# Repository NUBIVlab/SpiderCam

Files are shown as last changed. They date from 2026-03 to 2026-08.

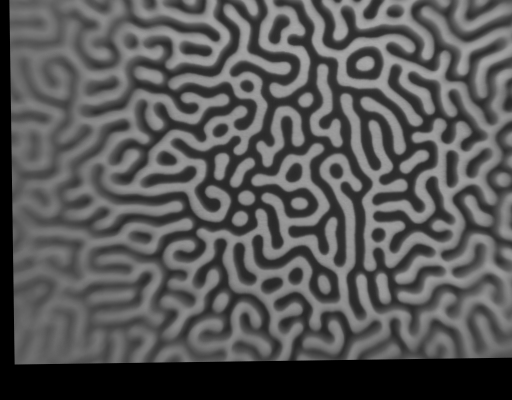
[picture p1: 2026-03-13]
fpga/tb/dfdd_tb/test_images/capture_22_camera1.png

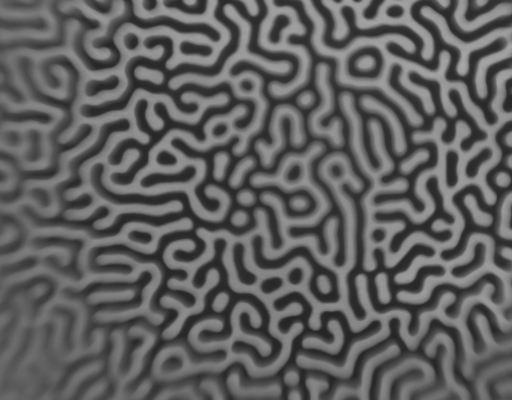
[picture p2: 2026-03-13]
fpga/tb/dfdd_tb/test_images/capture_22_camera0.png

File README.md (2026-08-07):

## [CVPR 2026] SpiderCam: Low-Power Snapshot Depth from Differential Defocus

<b>[Marcos A. Ferreira](https://marc103.github.io/)</b><sup>&ast;,1</sup>, <b>[Tianao Li](https://lukeli0425.github.io/)</b><sup>&ast;,1</sup>, <b>[John Mamish](https://scholar.google.com/citations?user=ux9iJ74AAAAJ&hl=en)</b><sup>&ast;,2</sup>, <b>[Josiah Hester](https://josiahhester.com/)</b><sup>2</sup>, <b>[Yaman Sangar](https://scholar.google.com/citations?user=gbBJzRkAAAAJ&hl=en&oi=ao)</b><sup>2</sup>, <b>[Qi Guo](https://www.qiguo.org/)</b><sup>3</sup>, <b>[Emma Alexander](https://www.alexander.vision/emma)</b><sup>1</sup>
<br>
<sup>1</sup>Northwestern University, <sup>2</sup>Georgia Institute of Technology, <sup>3</sup>Purdue University, <sup>&ast;</sup>Equal contribution.

_IEEE/CVF Conference on Computer Vision and Pattern Recognition (CVPR), 2026_

&nbsp;
&nbsp;
&nbsp;
&nbsp;

Official code for [_SpiderCam: Low-Power Snapshot Depth from Differential Defocus_](https://nubivlab.github.io/SpiderCam/).

Pipeline

### Repository layout

| Path | Contents |
| --- | --- |
| [`configs/`](configs/), [`datasets/`](datasets/), [`models/`](models/), [`utils/`](utils/) | Hydra configs and DfDD training / inference code |
| [`serialcam_ft232h/`](serialcam_ft232h/) | Live FT232H stream viewer and on-device DfDD parameter UI |
| [`fpga/`](fpga/) | FPGA RTL (see [`fpga/README.md`](fpga/README.md)) |
| [`pcb/`](pcb/) | PCB layouts |
| [`3d_printed_parts/`](3d_printed_parts/) | Printable enclosure parts |

### Running DfDD

#### Setup

To install required packages:
```bash
pip install -r requirements.txt
```

#### Data

Point `data_path` in a config under [`configs/data/`](configs/data/) to your capture directory. Each group folder should contain paired frames:

- `cam_1_500_480_{idx}.png` — near-focus (`+`) image  
- `cam_0_500_480_{idx}.png` — far-focus (`-`) image  

Crop, frame range, depth step/offset, and image center are set in the same YAML (see e.g. [`configs/data/11-06.yaml`](configs/data/11-06.yaml)).

#### Model parameters

Defaults live in [`configs/model/focal_split.yaml`](configs/model/focal_split.yaml). Override any of them on the CLI with Hydra (`model.<key>=...`).

| Parameter | Options / typical values | Meaning |
| --- | --- | --- |
| `model.n_scales` | `1` or `2` | Number of Laplacian-pyramid levels. Depth is estimated at each scale and fused; `2` is the paper default and improves robustness across texture frequencies. |
| `model.dxdy` | `true` / `false` | If `true`, append spatial derivatives (`∂/∂x`, `∂/∂y`) of `V` and `W` as extra channels before fusion (3 channels per scale). Helps on oriented textures. |
| `model.const` | `rings`, `universal`, `radial`, `polynomial`, `pixel-grid` | How optical constants **A** and **B** vary over the field of view (see below). |
| `model.n_rings` | e.g. `16` | Used when `const=rings`: number of concentric annuli with a shared (A, B) per ring. |
| `model.n_orders` | e.g. `2` | Used when `const=radial` or `polynomial`: polynomial degree of the radial / 2D field. |
| `model.conf` | `VW`, `W2`, `V`, `W` | Confidence map used for sparsity filtering and (in `separate` mode) scale fusion. |
| `model.mode` | `joint` / `separate` | How multi-channel estimates are fused (see below). |

**Optical constants (`model.const`).** DfDD recovers depth from a linear combination of the image Laplacian and the differential image, with learnable maps **A** and **B** (one pair per scale):

- `universal` — single scalar (A, B) per scale (spatially constant; ablation / simplest FPGA mapping).
- `rings` — piecewise-constant (A, B) on concentric rings about `data.center` (paper default; matches on-device zone tables).
- `radial` — A(r), B(r) as low-order polynomials in image radius.
- `polynomial` — full 2D polynomial in (x, y).
- `pixel-grid` — independent (A, B) at every pixel (most flexible, heaviest).

**Confidence (`model.conf`).** With numerator/denominator terms built from `V` and `W`:

- `VW` — confidence ∝ `V·W` (paper default; aligns with the depth numerator).
- `W2` — confidence ∝ `W²` (denominator energy).
- `V` / `W` — confidence ∝ `|V|` or `|W|`.

Higher confidence pixels are kept when evaluating at a given sparsity (see `optim.sparsity`).

**Fusion (`model.mode`).** Softmax weights `ω` combine channels across scales (and dx/dy if enabled):

- `joint` — fuse numerator and denominator first, then divide (more stable; default).
- `separate` — form a depth map per channel, then confidence-weighted average.

**Paper setting (recommended start):**

```text
model.n_scales=2 model.dxdy=true model.mode=joint model.const=rings model.n_rings=16 model.conf=VW
```

#### Train

Calibrate / train optical constants with Hydra overrides:

```bash
python train_focal_split.py data=11-06 data.group=texture1 \
  model.n_scales=2 model.dxdy=true model.mode=joint model.const=rings model.n_rings=16 \
  model.conf=VW
```

Checkpoints and logs are written under `./results/`. For the full ablation suite used in the paper, see [`train.sh`](train.sh).

#### Evaluate

After training, run inference with the same data/model/optim settings (must match the trained checkpoint path):

```bash
python run_focal_split.py data=11-06 data.group=texture1 \
  model.n_scales=2 model.dxdy=true model.mode=joint model.const=rings model.n_rings=16 \
  model.conf=VW
```

This loads `checkpoint_{n_epochs}epochs.pth`, reports MAE/MSE and working range at several sparsities, and saves heatmaps / depth maps under `./results/`.

#### Live hardware (optional)

With the SpiderCam FPGA connected over FT232H:

```bash
python serialcam_ft232h/serialcam_stream_ft232h.py
```

Requires the `serialcam` stack (PyQt5, `ftd2xx`). Use **Set DfDD Parameters** in the viewer to push A/B/ω and confidence thresholds to the device. 
<!-- PCB layouts, FPGA RTL, and printable enclosure parts are under [`pcb/`](pcb/), [`fpga/`](fpga/), and [`3d_printed_parts/`](3d_printed_parts/). -->

### Citation

```bibtex
@InProceedings{ferreira2026spidercam,
    author    = {Ferreira, Marcos A. and Li, Tianao and Mamish, John and Hester, Josiah and Sangar, Yaman and Guo, Qi and Alexander, Emma},
    title     = {SpiderCam: Low-Power Snapshot Depth from Differential Defocus},
    booktitle = {Proceedings of the IEEE/CVF Conference on Computer Vision and Pattern Recognition (CVPR)},
    month     = {June},
    year      = {2026},
    pages     = {41699-41709}
}
```

### Acknowledgment

This research was partially supported by the National Science Foundation under award numbers CNS-2430327 and CCF-2431505. Any opinions, findings, conclusions, or recommendations expressed in this material are those of the authors and do not necessarily reflect the views of the National Science Foundation or other supporters. We would also like to thank [Junjie Luo](https://luo-jun-jie.github.io/) and [Alan Fu](https://www.linkedin.com/in/alan-fu-a100b91a5/) for helpful discussions.

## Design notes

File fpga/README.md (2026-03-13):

# Floating Point Image Processing SV RTL

Contains parameterized floating point\
- adder\
- multiplier\
- divider

Parameterized as in you can select a custom number of bits for exponent
and fractional parts i.e to support FP16 or FP32 (or anything above and
in between like FP24). It's almost to the IEEE-754 with the exceptions
of disabling subnormal number support and the rounding isn't perfect
(ties always round up and instead of having a round and guard bit, there
is just a round bit). This was done to make it more area efficient when
deploying on FPGA platforms.

There is also the modules\
- window fetcher\
- convolution floating point

The window fetcher grabs a window of values from a data stream (such as
a pixel stream). The convolution module takes a window of values and a
kernel and performs the convolution (MAC operation). Since kernels are
often sparse matrices and/or with powers of 2, there is also the
`optimal_convolution_floating_point_generator.py` in the tools folder
which generates the necessary wrappers to optimize away 0 values for
multiplies and consequently the sparse adder trees. View the python file
itself to see how to call it.

By combining these building blocks modules, we can build networks of
convolution filters with the data streaming model. This is showcased in
the DfDD project.

------------------------------------------------------------------------

# Folder Structure

### rtl

Contains RTL code.

### → third_party

Contains third party RTL code.

### → verify_files

Verifying that my floating point modules are correct is tricky business.
Thus on top of using formal equivalence verification (by comparing my
results to the CPU's results), I also wrote these informal
`verify_files` that detail steps I took, which I then proof read some
number of times.

### tb

Contains all relevant testbench code done using Formal Equivalence
Verification (FEV). This is a fancy way of saying I compared the DUT
results to theoretical golden models as a verification methodology. It
is structured and decoupled in a way that makes most sense to me and is
generally applicable.

### → components

Organized the standard components that using the OOP part of
SystemVerilog is built and quite handy for; drivers, generators, golden
models, interfaces, monitors, scoreboards and utilities, package
manager.

Very briefly, it follows the Bus Functional Model (BFM) where you pass
the main interface as a virtual interface to the named components and
connect these components via blocking queues as seen in each of the
`*_tb` subfolders that correspond to the DUT.

### → \*\_tb/simulate

Contains the script to run the simulation on ModelSim (specifically
through Diamond).

### synth

This contains all the synthesis folders. The synthesis folders contain
the final `top` files and various scripts to perform synthesis.

In this case, the folders are targeted towards the ECP5 FPGA using
Yosys's Trellis Project + Nextpnr\
https://github.com/YosysHQ/prjtrellis

### Tools

Mainly python scripts that do useful things (like my optimal convolution
generator) and miscellaneous tasks.

------------------------------------------------------------------------

# Bitstreams and Running the GUI

The FPGA bitstream used to program the board must correspond to how the
GUI is configured. The GUI expects a specific data format depending on
which processing pipeline is programmed onto the FPGA.

## Bitstream Variants

### dual_scale → dxdy → radial → pre → top.bit

This bitstream configures the pipeline with:

-   Dual-scale network enabled\
-   `dx` and `dy` filters enabled\
-   Radial `a/b` terms enabled\
-   Preprocessing performed in hardware\
-   Slow frame rate mode

Outputs **two windows**:

-   `cam_0`
-   Depth output

------------------------------------------------------------------------

### dual_scale → pass → simple → nopre → top.bit

This bitstream configures the pipeline with:

-   Dual-scale network enabled\
-   `dx` and `dy` filters disabled\
-   Single (non-radial) `a/b` term\
-   No preprocessing\
-   Slow frame rate mode

Outputs **two windows**:

-   `cam_0`
-   Depth output

------------------------------------------------------------------------

### camera_previewer → top.bit

This bitstream encodes logic that simply passes through `cam_0` and
`cam_1` without any processing.

It runs at slow frame rate and outputs **two windows**.

This configuration is useful when capturing raw sensor data for
processing or performing homography calibration between the two cameras.

------------------------------------------------------------------------

### pre_fast variants

The `pre_fast` versions enable the high frame rate pipeline (\~30 FPS).

In this configuration the system outputs **a single window** containing
only the depth output.

------------------------------------------------------------------------

# Running the GUI

Depending on the programmed bitstream, the GUI must be launched with the
correct number of channels and frame-rate mode.

### Two output windows (slow frame rate mode)

``` bash
python .\serialcam_stream_ft232h.py --width 500 --height 480 --maxchannels 2 --fast 0
```

Displays:

-   `cam_0`
-   depth output

------------------------------------------------------------------------

### One output window (fast frame rate mode)

``` bash
python .\serialcam_stream_ft232h.py --width 500 --height 480 --maxchannels 1 --fast 1
```

Displays:

-   depth output only (high frame rate mode)

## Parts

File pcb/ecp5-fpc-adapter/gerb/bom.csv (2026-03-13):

Reference | Value | Datasheet | Footprint | Qty | DNP
C1,C2,C3,C4 | 10u | ~ | Capacitor_SMD:C_0603_1608Metric_Pad1.08x0.95mm_HandSolder | 4
C5,C6,C7,C8,C9,C10 | 1u | ~ | Capacitor_SMD:C_0603_1608Metric_Pad1.08x0.95mm_HandSolder | 6
J1,J2 | Conn_02x20_Odd_Even | ~ | Connector_PinHeader_2.54mm:PinHeader_2x20_P2.54mm_Vertical | 2
J3,J4 | 5051103091 | 5051103091 | molex_5051:CON_5051103091_MOL | 2
J5,J6,J7 | Conn_01x02_Pin | ~ | Connector_PinHeader_2.54mm:PinHeader_1x02_P2.54mm_Vertical | 3
JP1,JP4,JP5,JP7,JP8,JP9,JP10,JP11,JP12,JP13,JP15 | Jumper_2_Small_Open | ~ | Jumper:SolderJumper-2_P1.3mm_Open_RoundedPad1.0x1.5mm | 11
JP2,JP3,JP6,JP14 | Jumper_2_Small_Bridged | ~ | Jumper:SolderJumper-2_P1.3mm_Bridged_RoundedPad1.0x1.5mm | 4
L1,L2 | 2.2u | ~ | L_2016:IND_DFE2016_MUR | 2
R4,R5,R6,R7 | 10k | ~ | Resistor_SMD:R_0603_1608Metric_Pad0.98x0.95mm_HandSolder | 4
R12,R14,R19,R21 | 100k | ~ | Resistor_SMD:R_0603_1608Metric_Pad0.98x0.95mm_HandSolder | 4
R13 | 28.7k | ~ | Resistor_SMD:R_0603_1608Metric_Pad0.98x0.95mm_HandSolder | 1
R15,R20,R26 | 0 | ~ | Resistor_SMD:R_0603_1608Metric_Pad0.98x0.95mm_HandSolder | 3
R22 | 12k | ~ | Resistor_SMD:R_0603_1608Metric_Pad0.98x0.95mm_HandSolder | 1
R23 | 2k | ~ | Resistor_SMD:R_0603_1608Metric_Pad0.98x0.95mm_HandSolder | 1
U1,U2 | TPS62841DLCR | TPS62840DLCR | tps62840:VSON8_2P1X1P6_TEX | 2
U3 | AP7331-SNG-7 |  | AP7331-SNG-7:DFN200X200X60-8N | 1

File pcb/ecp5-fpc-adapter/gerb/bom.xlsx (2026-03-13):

Reference | Value | Datasheet | Footprint | Qty | mfr pn
C1,C2,C3,C4 | 10u | ~ | Capacitor_SMD:C_0603_1608Metric_Pad1.08x0.95mm_HandSolder | 4 | CL10A106MA8NRNC
C5,C6,C7,C8,C9,C10 | 1u | ~ | Capacitor_SMD:C_0603_1608Metric_Pad1.08x0.95mm_HandSolder | 6 | CL10B105KO8NNNC
J1,J2 | Conn_02x20_Odd_Even | ~ | Connector_PinHeader_2.54mm:PinHeader_2x20_P2.54mm_Vertical | 2 | PPTC202LFBN-RC
J1,J2 |  |  |  | 1 | ESQ-120-14-T-D
J3,J4 | 5051103091 | 5051103091 | molex_5051:CON_5051103091_MOL | 2 | 5051103091
J5,J6,J7 | Conn_01x02_Pin | ~ | Connector_PinHeader_2.54mm:PinHeader_1x02_P2.54mm_Vertical | 3 | M20-9990245
jumper |  |  |  | 10 | QPC02SXGN-RC
L1,L2 | 2.2u | ~ | L_2016:IND_DFE2016_MUR | 2 | DFE201612E-2R2M=P2
R4,R5,R6,R7 | 10k | ~ | Resistor_SMD:R_0603_1608Metric_Pad0.98x0.95mm_HandSolder | 4 | RC0603FR-0710KL
R12,R14,R19,R21 | 100k | ~ | Resistor_SMD:R_0603_1608Metric_Pad0.98x0.95mm_HandSolder | 4 | RC0603FR-07100KL
R13 | 28.7k | ~ | Resistor_SMD:R_0603_1608Metric_Pad0.98x0.95mm_HandSolder | 1 | RC0603FR-0728K7L
R15,R20,R26 | 0 | ~ | Resistor_SMD:R_0603_1608Metric_Pad0.98x0.95mm_HandSolder | 3 | RC0603JR-070RL
R22 | 12k | ~ | Resistor_SMD:R_0603_1608Metric_Pad0.98x0.95mm_HandSolder | 1 | RC0603FR-0712KL
R23 | 2k | ~ | Resistor_SMD:R_0603_1608Metric_Pad0.98x0.95mm_HandSolder | 1 | RC0603FR-072KL
U1,U2 | TPS62841DLCR | TPS62840DLCR | tps62840:VSON8_2P1X1P6_TEX | 2 | TPS62840DLCR
U3 | AP7331-SNG-7 |  | AP7331-SNG-7:DFN200X200X60-8N | 1 | AP7331-SNG-7

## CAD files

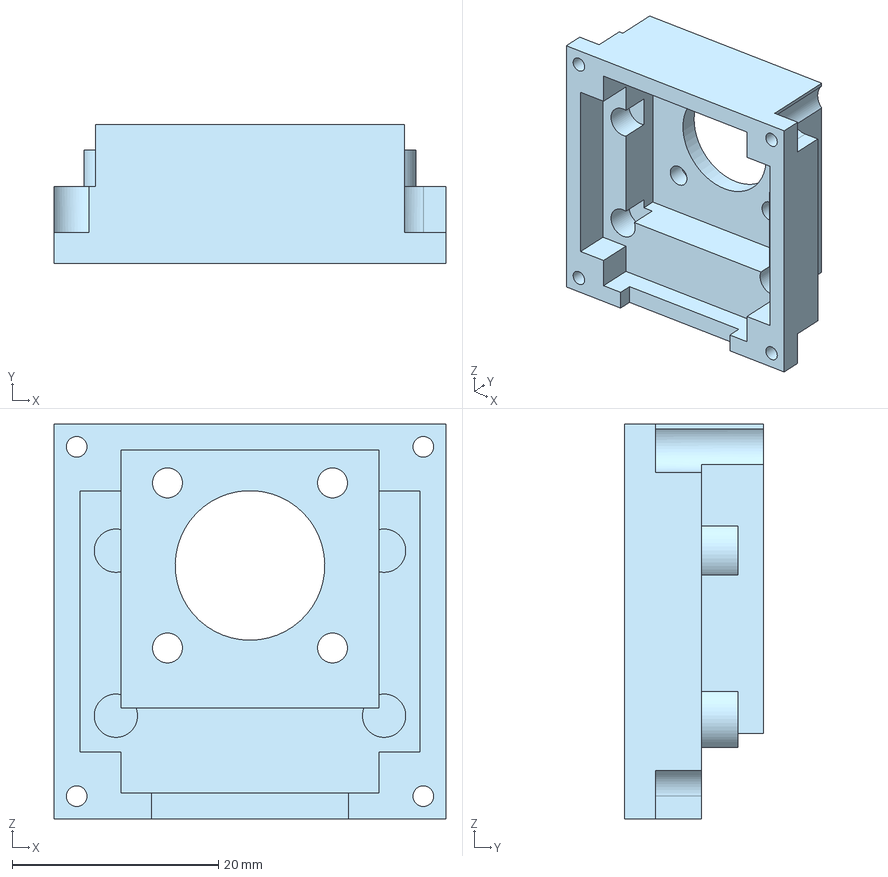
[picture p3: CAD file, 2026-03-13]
3d_printed_parts/dual-sensor-enclosure/Beamsplitter_direct_mount_Baffle.step
38.0 x 13.5 x 38.3 mm

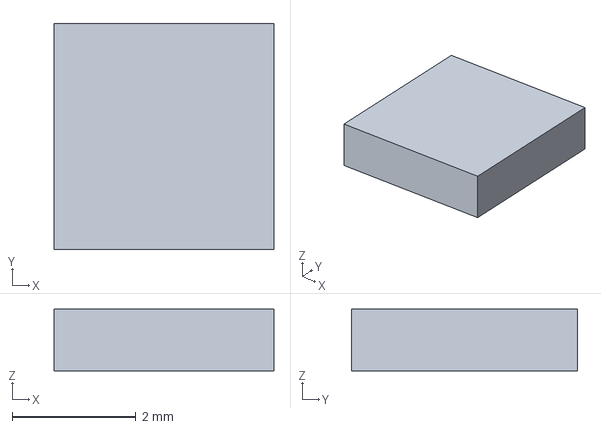
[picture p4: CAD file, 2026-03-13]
pcb/hm0360-carrier/himax_step/hm0360_box.step
3.55 x 3.65 x 1.00 mm

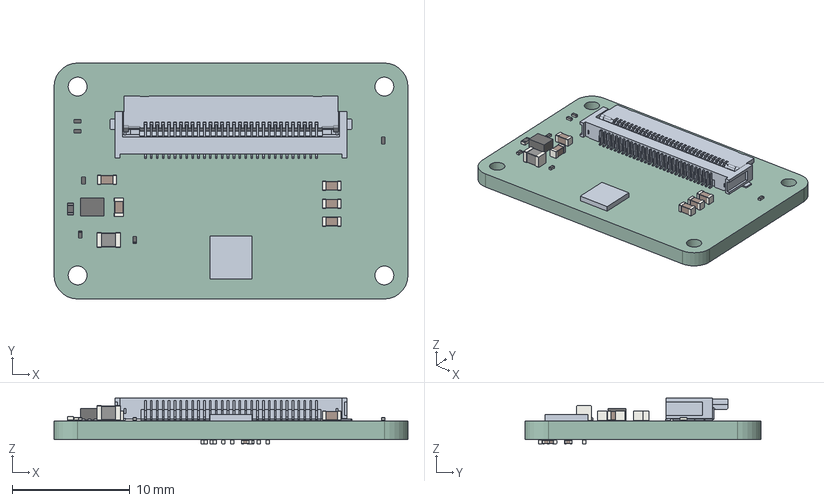
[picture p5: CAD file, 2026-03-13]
pcb/hm0360-carrier/hm0360_breakout.step
30.0 x 20.0 x 3.86 mm
R_0402_1005Metric
C_0603_1608Metric x 5
R_0201_0603Metric x 6
L_0805_2012Metric
DLC0008B_ASM
C_0201_0603Metric x 12
hm0360_breakout_PCB

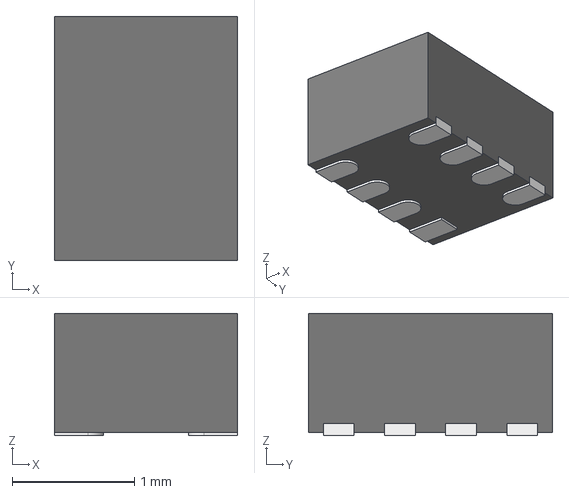
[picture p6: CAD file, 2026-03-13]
pcb/hm0360-carrier/TPS62840DLCR/DLC0008B.stp
1.50 x 2.00 x 1.00 mm
FRAME
MOLD

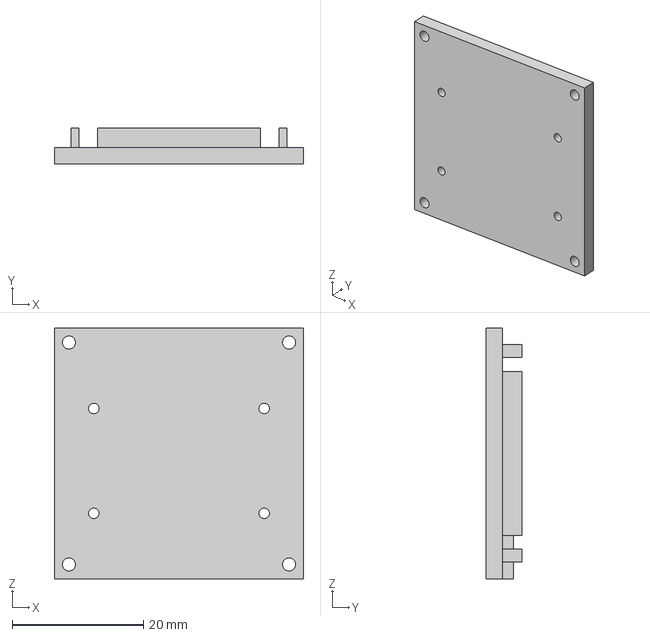
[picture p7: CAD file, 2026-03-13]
3d_printed_parts/dual-sensor-enclosure/Beamsplitter_direct_mount_iris_Lid.step
38.0 x 5.50 x 38.3 mm

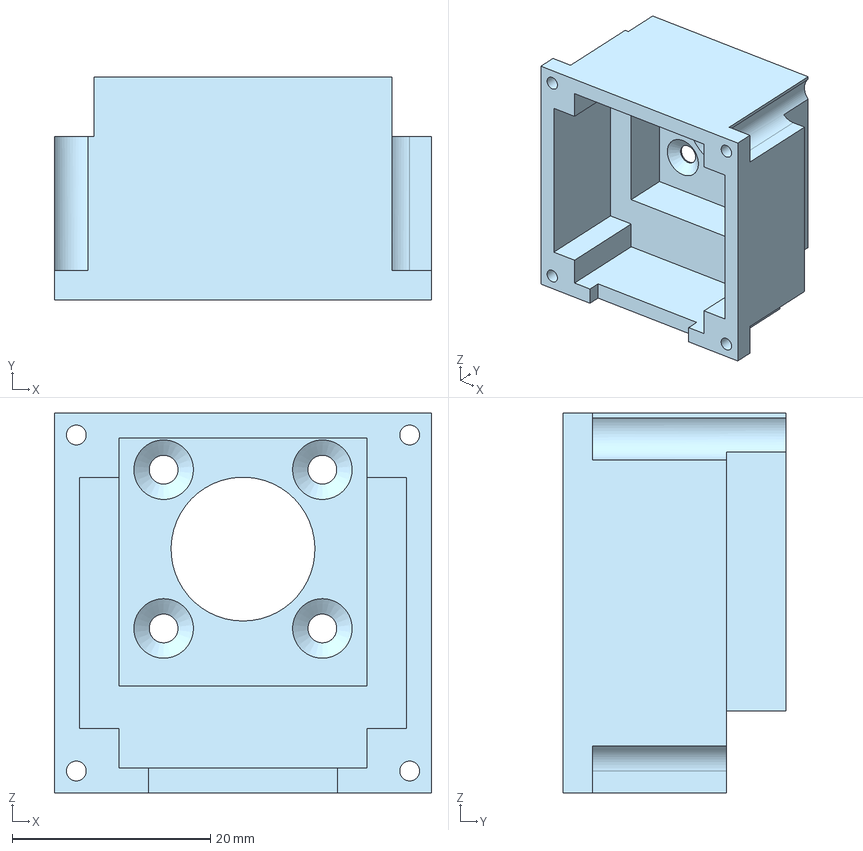
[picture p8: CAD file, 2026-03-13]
3d_printed_parts/dual-sensor-enclosure/Beamsplitter_direct_mount_iris_Baffle.step
38.0 x 22.5 x 38.3 mm

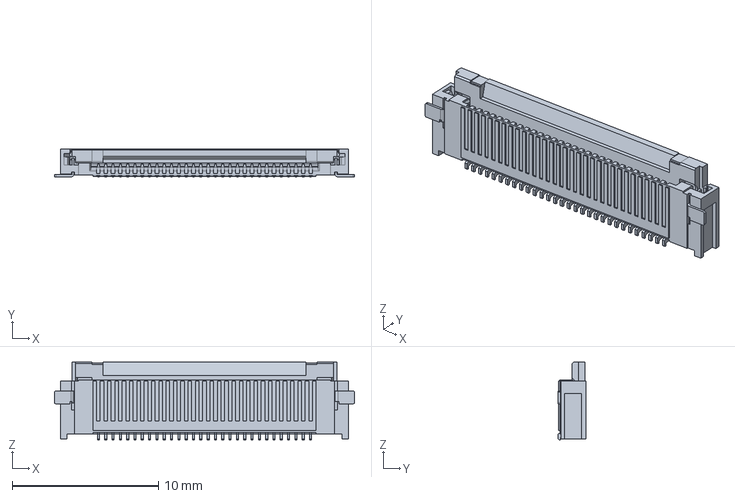
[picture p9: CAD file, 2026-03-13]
pcb/hm0360-carrier/molex_5051103091/5051103091.stp
20.5 x 1.90 x 5.30 mm

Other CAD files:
3d_printed_parts/dual-sensor-enclosure/Beamsplitter_direct_mount_Lid.step

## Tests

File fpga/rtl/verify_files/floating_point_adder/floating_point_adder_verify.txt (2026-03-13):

Floating Point Adder

Specification:
- Wire up all the pieces in the following order:
1. sgm - select greater magnitude
2. ngm - normalize greater magnitude
x x x 3. rnv - round normalized value x x x
3. cvt - convert to signed 
4. avt - add values together
5. cvu - convert to unsigned 
6. nr  - normalize result
7. rr  - round result 

Modification:
- previously I thought the rounding at rnv was necessary
but actually it is premature. Instead it is better to allow
the addition to happen first and let the final rounding do
the job. Therefore, 'rnv' has been removed adnt this is now
a 7 stage pipelined adder.

Parameters:
- EXP_WIDTH,  width of exponent part                                    
- FRAC_WIDTH, width of fractional part

'Local' Parameters:                                                                
- FP_WIDTH_TOT, width of total form fp
    -> 1 + EXP_WIDTH + FRAC_EX_WIDTH                            _*_                           
- FP_WIDTH_REG, width of regular form fp 
    -> 1 + EXP_WIDTH + 1 + 1 + FRAC_WIDTH + 1                   _*_

IO:
- check widths                                                  _*_

Wiring:
- naming convention is from_to_*_w                              _*_
- check 1 wires - sgm
    - parameters                                                _*_
    - widths                                                    _*_
    - names                                                     _*_
- check 2 wires - ngm
    - parameters                                                _*_
    - widths                                                    _*_
    - names                                                     _*_
- check 3 wires - cvt
    - parameters                                                _*_
    - widths                                                    _*_
    - names                                                     _*_
- check 4 wires - avt
    - parameters                                                _*_                         
    - widths                                                    _*_
    - names                                                     _*_
- check 5 wires - cvu
    - parameters                                                _*_                                                   
    - widths                                                    _*_
    - names                                                     _*_ 
- check 6 wires - nr
    - parameters                                                _*_
    - widths                                                    _*_
    - names                                                     _*_
- check 7 wires - rr
    - parameters                                                _*_
    - widths                                                    _*_
    - names                                                     _*_
- check clk_i and rst_i for all                                 _*_

Output:
- check output of rr to top out                                 _*_

Log:
- floating point adder has been verfied once by me (7/10/25)

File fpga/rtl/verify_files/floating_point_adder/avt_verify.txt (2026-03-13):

Add Values Together

Specification:
- given fp_a_i and fp_b_i in total form add them
  together and output the result
- output fp_a_sign and fp_b_sign, this will be necessary
 for cvu (next stage) to determine how to interpret the
 carry bit

Descriptions:
- frac ex (expand) describes carry bit, lead bit, frac bits and round bit
  in that order.
- it's just a way to break up the full form into pieces:
    {sign bit, exp bits, frac ex bits} for ease of use

Parameters:
- EXP_WIDTH,  width of exponent part                                    
- FRAC_WIDTH, width of fractional part                                  

'Local' Parameters:
- FRAC_EX_WIDTH, width of frac ex                       
    -> 1 + 1 + FRAC_WIDTH + 1                                           _*_ _*_                                   
- FRAC_EX_IDX_LSB, lsb index of frac ex 
    -> 0                                                                _*_ _*_                                            
- FRAC_EX_IDX_MSB, msb index of frac ex
    -> FRAC_EX_WIDTH + FRAC_EX_IDX_LSB - 1                              _*_ _*_                      
- EXP_IDX_LSB, lsb index of exp ex
    -> FRAC_EX_WIDTH                                                    _*_ _*_                                                                               
- EXP_IDX_MSB, msb index of exp ex
    -> EXP_WIDTH + EXP_IDX_LSB - 1                                      _*_ _*_                                 
- SIGN_IDX, index of sign bit
    -> EXP_WIDTH + FRAC_EX_WIDTH                                        _*_ _*_                      
- FP_WIDTH_TOT, width of total form fp
    -> 1 + EXP_WIDTH + FRAC_EX_WIDTH                                    _*_ _*_

IO:
- check widths                                                          _*_ _*_ 

Input Registers:
- check widths                                                          _*_ _*_
- fp_a_reg samples fp_a_i @ clk_i                                       _*_ _*_
- fp_b_reg samples fp_b_i @ clk_i                                       _*_ _*_
- if rst_i is high, valid_reg samples 0       @ clk_i                   _*_ _*_
- if rst_i is low,  valid_reg samples valid_i @ clk_i                   _*_ _*_

Main:   
- check widths                                                          _*_ _*_                                      
- sign, exp and frac_ex starting values for fp_*                        _*_ _*_
- sign, frac_ex starting for fp is set to 0s                            _*_ _*_        
- frac_exp for fp is set to fp_exp_a                                    _*_ _*_
- the logic is as such:
    - with the context of the previous round (cvt)                      _*_ _*_
    - the frac_ex values are in signed mode                             _*_ _*_
    - if the sign bits were different, the negative one                 
      is negative
    - if the sign bits are the same, both are positive                  _*_ _*_
    - meaning, if the sign bits are the same, if they are               _*_ _*_
      added, the carry bit is a genuine carry bit
    - if the sign bits are different,                                   _*_ _*_
        - an overflow is impossible, since one value is positive
          and the other negative
        - the carry bit actually represents the resulting sign
          of the addition
    - this also means, for the output, we need to pass the              _*_ _*_
      fp_a_sign adn fp_b_sign, so the next stage knows how
    - to interpret it
    - + is fine                                                         _*_ _*_

Output:
- fp_o is concatenation of fp_sign, fp_exp and fp_frac_exp              _*_ _*_
- fp_a_sign_o is fp_a_sign                                              _*_ _*_
- fp_b_sign_o is fp_b_sign                                              _*_ _*_
- valid_o is valid_reg                                                  _*_ _*_

Log:
- avt has been verified by me (7/9/25)
- avt has been verified by me (7/14/25)

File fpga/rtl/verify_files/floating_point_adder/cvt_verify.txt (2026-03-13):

Convert to signed

Specification:
- given fp_a_i and fp_b_i in total form, using the sign bits, convert
  the frac exp of each to its signed version if the sign bits differ, 
  in prepartion for the addition step

Descriptions:
- frac ex (expand) describes carry bit, lead bit, frac bits and round bit
  in that order.
- it's just a way to break up the full form into pieces:
    {sign bit, exp bits, frac ex bits} for ease of use

Parameters:
- EXP_WIDTH,  width of exponent part                                    
- FRAC_WIDTH, width of fractional part                                  

'Local' Parameters:
- FRAC_EX_WIDTH, width of frac ex                       
    -> 1 + 1 + FRAC_WIDTH + 1                                           _*_ _*_           
- FRAC_EX_IDX_LSB, lsb index of frac ex 
    -> 0                                                                _*_ _*_
- FRAC_EX_IDX_MSB, msb index of frac ex
    -> FRAC_EX_WIDTH + FRAC_EX_IDX_LSB - 1                              _*_ _*_
- EXP_IDX_LSB, lsb index of exp ex
    -> FRAC_EX_WIDTH                                                    _*_ _*_                                          
- EXP_IDX_MSB, msb index of exp ex
    -> EXP_WIDTH + EXP_IDX_LSB - 1                                      _*_ _*_
- SIGN_IDX, index of sign bit
    -> EXP_WIDTH + FRAC_EX_WIDTH                                        _*_ _*_
- FP_WIDTH_TOT, width of total form fp
    -> 1 + EXP_WIDTH + FRAC_EX_WIDTH                                    _*_ _*_

IO:
- check widths                                                          _*_ _*_

Input Registers:
- check widths                                                          _*_ _*_
- fp_a_reg samples fp_a_i @ clk_i                                       _*_ _*_
- fp_b_reg samples fp_b_i @ clk_i                                       _*_ _*_
- if rst_i is high, valid_reg samples 0       @ clk_i                   _*_ _*_
- if rst_i is low,  valid_reg samples valid_i @ clk_i                   _*_ _*_

Main:
- check widths                                                          _*_ _*_
- sign, exp and frac_ex starting values                                 _*_ _*_

then

- the logic is as such:
    - with the context of the previous round (rnv)                      _*_ _*_
    - carry bit is 0                                                    _*_ _*_
    - lead bit is either 1 or 0                                         _*_ _*_
    - if the sign bits are the same, then we can maintain               _*_ _*_
      both frac ex as they are
    - if the sign bits differ, then the negative sign one needs         _*_ _*_
      to be converted by performing complement + 1
    - the idea here is adding the frac ex directly is fine              _*_ _*_
      when the signs are the same (it's just magnitudes). If they
      differ, one being converted will guarantee that when they are
      added together, than an overflow will not occur since we
      are adding a positive and negative value together.
    - We can then use the sign bits to determine later whether          _*_ _*_
      the carry bit should be interpreted as an actual carry bit
      or sign bit (as will be written in the avt_verify.txt file)
    - ~ is fine                                                         _*_ _*_
    - + 1 is fine                                                       _*_ _*_
    - != is fine                                                        _*_ _*_
 
Output:
- fp_*_o is the concatenation of fp_*_sign, fp_*_exp and fp_*_frac_ex   _*_ _*_
- valid_o is valid_reg                                                  _*_ _*_

Log:
- cvt has been verified by me (7/9/25)
- cvt has been verified by me (7/14/25)

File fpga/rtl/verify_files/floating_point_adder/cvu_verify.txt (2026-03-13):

Convert to unsigned

Specification:
- given fp_i, fp_a_sign_i, fp_b_sign_i, using the sign bits
  fp_frac_ex to a positive value and determine the Finally
  resulting sign bit.

Descriptions:
- frac ex (expand) describes carry bit, lead bit, frac bits and round bit
  in that order.
- it's just a way to break up the full form into pieces:
    {sign bit, exp bits, frac ex bits} for ease of use

Parameters:
- EXP_WIDTH,  width of exponent part                                    
- FRAC_WIDTH, width of fractional part                                  

'Local' Parameters:
- FRAC_EX_WIDTH, width of frac ex                       
    -> 1 + 1 + FRAC_WIDTH + 1                                           _*_ _*_                                             
- FRAC_EX_IDX_LSB, lsb index of frac ex 
    -> 0                                                                _*_ _*_                                                                     
- FRAC_EX_IDX_MSB, msb index of frac ex
    -> FRAC_EX_WIDTH + FRAC_EX_IDX_LSB - 1                              _*_ _*_                                                   
- EXP_IDX_LSB, lsb index of exp ex
    -> FRAC_EX_WIDTH                                                    _*_ _*_                                                                                                 
- EXP_IDX_MSB, msb index of exp ex
    -> EXP_WIDTH + EXP_IDX_LSB - 1                                      _*_ _*_                                                      
- SIGN_IDX, index of sign bit
    -> EXP_WIDTH + FRAC_EX_WIDTH                                        _*_ _*_                                         
- FP_WIDTH_TOT, width of total form fp
    -> 1 + EXP_WIDTH + FRAC_EX_WIDTH                                    _*_ _*_
- CARRY_IDX, idx of carry bit
    -> 1 + FRAC_WIDTH + 1                                               _*_ _*_

IO:
- check widths                                                          _*_ _*_                                         

Input Registers:
- check widths                                                          _*_ _*_                                           
- fp_reg samples fp_i @ clk_i                                           _*_ _*_
- fp_a_sign_reg samples fp_a_sign_i @ clk_i                             _*_ _*_                             
- fp_b_sign_reg smaples fp_b_sign_i @ clk_i                             _*_ _*_
- if rst_i is high, valid_reg samples 0       @ clk_i                   _*_ _*_             
- if rst_i is low,  valid_reg samples valid_i @ clk_i                   _*_ _*_
 
Main:
- check widths                                                          _*_ _*_
- sign, exp, frac_ex starting values for fp_*                           _*_ _*_
- The logic is as such:
    - fp_*_frac_ex are in signed mode, if both sign bits are equal,     _*_ _*_
      resulting carry bit represents an actual carry bit
      - in this case, no conversion is necessary                        _*_ _*_
      - the result sign bit is fp_a_sign_reg                            _*_ _*_
    - if the bits are different, the carry bit represents a sign bit
      - in this case, if the carry bit is 1 (meaning negative value),
        we need to do complemenet + 1 to convert it to positive value   _*_ _*_
        - this also means the result sign bit is 1                      _*_ _*_
      - converting a negative value to positive will never cause an
        overflow, since you can convert a signed value to unsigned
        in the same number of bits                                      _*_ _*_
      - if the carry bit is zero, it is a positive value, no need to    _*_ _*_
        convert
        - this also means the result sign bit is 0                      _*_ _*_
      - There is another important check, if it turns out the result
        is zero, we need to set fp_exp to 0                             _*_ _*_
    
Output
- fp_o is the concatenation of fp_sign, fp_exp and fp_frac_exp          _*_ _*_
- valid_o is valid_reg                                                  _*_ _*_

Log:
- cvu has been verified by me (7/9/25)
- cvu has been verified by me (7/14/25)

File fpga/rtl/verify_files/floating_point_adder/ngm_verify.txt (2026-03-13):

Normalize to Greater Magnitude

Specification:
- given fp_a_i and fp_b_i in total form, where fp_a_i is
guaranteed to have the bigger or equal exponent, raise the exponent value
of fp_b_i to fp_a_i, using exp_diff_i
- output fp_a_o 
and the newly normalized fp_b_o
- output the valid signal, reset valid signal to 0 on reset.

Descriptions:
- frac ex (expand) describes carry bit, lead bit, frac bits and round bit
  in that order.
- it's just a way to break up the full form into pieces:
    {sign bit, exp bits, frac ex bits} for ease of use

Parameters:
- EXP_WIDTH,  width of exponent part                                    _*_
- FRAC_WIDTH, width of fractional part                                  _*_

'Local' Parameters:
- FRAC_EX_WIDTH, width of frac ex
    -> 1 + 1 + FRAC_WIDTH + 1                                           _*_ _*_
- FRAC_EX_IDX_LSB, lsb index of frac ex 
    -> 0                                                                _*_ _*_
- FRAC_EX_IDX_MSB, msb index of frac ex
    -> FRAC_EX_WIDTH + FRAC_EX_IDX_LSB - 1                              _*_ _*_
- EXP_IDX_LSB, lsb index of exp ex
    -> FRAC_EX_WIDTH                                                    _*_ _*_                                           
- EXP_IDX_MSB, msb index of exp ex
    -> EXP_WIDTH + EXP_IDX_LSB - 1                                      _*_ _*_
- SIGN_IDX, index of sign bit
    -> EXP_WIDTH + FRAC_EX_WIDTH                                        _*_ _*_
- FP_WIDTH_TOT, width of total form fp
    -> 1 + EXP_WIDTH + FRAC_EX_WIDTH                                    _*_ _*_                             

IO:
- check widths                                                          _*_ _*_

Input Registers:
- check widths                                                          _*_ _*_
- fp_*_reg samples fp_*_i         @ clk_i                               _*_ _*_
- exp_diff_reg samples exp_diff_i @ clk_i                               _*_ _*_
- if rst_i is high, valid_reg samples 0      @ clk_i                    _*_ _*_
- if rst_i is low, valid_reg samples valid_i @ clk_i                    _*_ _*_

Main:
- check widths                                                          _*_ _*_                         
- sign, exp and frac_ex starting values                                 _*_ _*_

then

- since we are raising fp_b_exp to fp_a_exp, we set fp_b_exp to
  fp_a_exp                                                              _*_ _*_

then

- frac ex consists of [carry bit | lead bit | frac bits | round bit ]   
    - we know the carry bit is zero (from sgm)                          _*_ _*_
    - that means, if we shift by frac bits + 1, the lead bit can end up _*_ _*_
      at the round bit
    - if we shift more than frac bits + 1, the result will be 0         _*_ _*_
    - hence only shift by exp_diff_reg bits if it is <= frac_bits + 1,  _*_ _*_
    - otherwise, set it to 0                                            _*_ _*_
    - a logical shift '>>' is correct here                              _*_ _*_
    - the idea is, for increasing the exponent by 1, we have to divide  _*_ _*_
      the frac ex by 2, hence the right shifting
    - exp_diff_reg must be declared as unsigned, since there is
      potential ambiguity of negative right shift (that could also      _*_ _*_
      cost more hardware), adn the <= comparison aswell.       

Output:
- fp_*_o is the concatenation of the fp_*_sign, fp_*_exp,               _*_ _*_
  fp_*_frac_ex.                                 
- valid_o is valid_reg                                                  _*_ _*_

Log:
- ngm has been verified by me (7/8/25)
- ngm has been verified by me (7/14/25)

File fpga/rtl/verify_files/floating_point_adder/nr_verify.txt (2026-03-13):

Normalize result

Specification:
- given fp_i, we need to normalize it such that the msb is stored
  at the lead bit location
- in this case, the msb refers to the first 1 bit found at the most
  significant bit position (not just the left most bit).

Descriptions:
- frac ex (expand) describes carry bit, lead bit, frac bits and round bit
  in that order.
- it's just a way to break up the full form into pieces:
    {sign bit, exp bits, frac ex bits} for ease of use

Parameters:
- EXP_WIDTH,  width of exponent part                                    
- FRAC_WIDTH, width of fractional part                                  

'Local' Parameters:
- FRAC_EX_WIDTH, width of frac ex                       
    -> 1 + 1 + FRAC_WIDTH + 1                                       _*_ _*_                                                                               
- FRAC_EX_IDX_LSB, lsb index of frac ex 
    -> 0                                                            _*_ _*_                                                                      
- FRAC_EX_IDX_MSB, msb index of frac ex
    -> FRAC_EX_WIDTH + FRAC_EX_IDX_LSB - 1                          _*_ _*_                                                    
- EXP_IDX_LSB, lsb index of exp ex
    -> FRAC_EX_WIDTH                                                _*_ _*_                                                                                                  
- EXP_IDX_MSB, msb index of exp ex
    -> EXP_WIDTH + EXP_IDX_LSB - 1                                  _*_ _*_                                                       
- SIGN_IDX, index of sign bit
    -> EXP_WIDTH + FRAC_EX_WIDTH                                    _*_ _*_                                          
- FP_WIDTH_TOT, width of total form fp
    -> 1 + EXP_WIDTH + FRAC_EX_WIDTH                                _*_ _*_ 
- CARRY_IDX, idx of carry bit
    -> 1 + FRAC_WIDTH + 1                                           _*_ _*_
- LEAD_IDX, idx of lead bit
    -> FRAC_WIDTH + 1                                               _*_ _*_
- EXP_MAX, max value of an exponent (INF)
    -> (2**EXP_WIDTH) - 1                                           _*_ _*_

IO:
- check widths                                                          

Input Registers:
- check widths                                                      _*_ _*_                                                      
- fp_reg samples fp_i @ clk_i                                       _*_ _*_     
- if rst_i is high, valid_reg samples 0       @ clk_i               _*_ _*_         
- if rst_i is low,  valid_reg samples valid_i @ clk_i               _*_ _*_    

Main:
- check widths                                                      _*_ _*_
- sign, exp and frac_ex starting values                             _*_ _*_
- check exp_const is exp starting value                             _*_ _*_
- check frac_ex_const is frac_ex starting value
- exp must be declared as unsigned                                  _*_ _*_                                 
- The logic is as such:
    - with the context of the previous round (cvu), we know         _*_ _*_
      it is in unsigned mode
    - We have to identify where the first 1 bit is located          _*_ _*_
      and do the appropriate shift
    - if the msb 1-bit is the carry bit, increase the exponent by 1 _*__*_
      and perform a right shift                                             
    - else if the msb 1-bit is the lead bit, do nothing             _*_ _*_
    - else if the msb 1-bit is the LEAD_IDX - 1 bit,                _*_ _*_
      decrease the exponent by 1, perform 1 left shift
    - else if the msb 1-bit is the LEAD_IDX - 2 bit,                _*_ _*_
      decrease the exponent by 2, peform 2 left shifts
    - written as the for loop i going from 0 -> LEAD_IDX - 1:       _*_ _*_
        - the number of left shifts is calculated as                _*_ _*_
          (LEAD_IDX - i) == ((FRAC_WIDTH + 1) - i)
        - we see that when i = 0, we shift by FRAC_WIDTH + 1        _*_ _*_    
          which is correct
        - the usage of fp_exp_cont and fp_exp_const and the         _*_ _*_
          ascending order of i means logically only the most 
          significant 1 bit found will be found.
            - specifically, all conditions are checked with         _*_ _*_
              the const values
            - all assignments are set with the const value          _*_ _*_
      ...
    - else if the msb 1-bit is the LEAD_IDX - (FRAC_WIDTH + 1),     
      which is the round bit, perform FRAC_WIDTH + 1  left shifts   _*_ _*_
      and decrease the exponent by FRAC_WIDTH + 1
    - else, there is no 1 bit, therefore this result is 0,          _*_ _*_
      meaning, set the exponent to 0
    - there is an additional issue, we have to guarantee that       _*_ _*_
      +/- to the exponent doesn't cause overflow/underflow and
      we also have to make sure that INF/NAN results are 
      preserved, meaning, an INF result can't be lowered
      back into a sensible result. We also have to treat the 
      'descent' into subnormal values properly. This is expensive,
      so instead, if subnormal is detected, we simply set the
      result to 0.
      - if exp is at INF, which is 2**(EXP_WIDTH) - 1,              _*_ _*_
        preserve it, else
        - carry bit scenario, +1, safe since it is within the       _*_ _*_
          outer if statement
        - LEAD_IDX - i scenario, if exp > (LEAD_IDX - i), this is   _*_ _*_
          fine, otherwise, set exp to 0, set frac_ex to 0
          - this includes when it is (FRAC_WIDTH + 1), the round    _*_ _*_
            bit scenario
        - else set exp to 0, set frac_ex to 0                       _*_ _*_
      - the outer if of exp INF is checked with exp_const and
        set accordingly as the last step                            _*_ _*_
    - '<<' is correct, logical shift fills 0 from right             _*_ _*_
    - '>>' is correct, logical shift fills 0 from left              _*_ _*_
    - '>' are correct, exp are explicitly unsigned                  _*_ _*_
    - '==' are correct, exp are explicitly unsigned                 _*_ _*_
    - using int in for loop is appropriate                          _*_ _*_
    - doing > (LEAD_IDX - i) is fine as there are enough
      bits and (LEAD_IDX - i) will never be negative                _*_ _*_

Output
- fp_o is the concatenation of fp_sign, fp_exp and fp_frac_exp      _*_ _*_      
- valid_o is valid_reg                                              _*_ _*_

Log:
- nr has been verified by me (7/10/25)
- nr has been verified by me (7/14/25)

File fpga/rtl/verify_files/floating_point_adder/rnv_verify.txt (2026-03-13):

Round Normalized Value  

Specification:
- given fp_a_i and fp_b_i in total form, round fp_b_i
- output the valid signal, reset valid signal to 0 on reset.

Descriptions:
- frac ex (expand) describes carry bit, lead bit, frac bits and round bit
  in that order.
- it's just a way to break up the full form into pieces:
    {sign bit, exp bits, frac ex bits} for ease of use

Parameters:
- EXP_WIDTH,  width of exponent part                                    _*_
- FRAC_WIDTH, width of fractional part                                  _*_

'Local' Parameters:
- FRAC_EX_WIDTH, width of frac ex
    -> 1 + 1 + FRAC_WIDTH + 1                                           _*_ _*_
- FRAC_EX_IDX_LSB, lsb index of frac ex 
    -> 0                                                                _*_ _*_
- FRAC_EX_IDX_MSB, msb index of frac ex
    -> FRAC_EX_WIDTH + FRAC_EX_IDX_LSB - 1                              _*_ _*_
- EXP_IDX_LSB, lsb index of exp ex
    -> FRAC_EX_WIDTH                                                    _*_ _*_                                          
- EXP_IDX_MSB, msb index of exp ex
    -> EXP_WIDTH + EXP_IDX_LSB - 1                                      _*_ _*_
- SIGN_IDX, index of sign bit
    -> EXP_WIDTH + FRAC_EX_WIDTH                                        _*_ _*_
- FP_WIDTH_TOT, width of total form fp
    -> 1 + EXP_WIDTH + FRAC_EX_WIDTH                                    _*_ _*_

IO:
- check widths                                                          _*_ _*_ 

Input Registers:
- check widths                                                          _*_ _*_
- fp_a_reg samples fp_a_i @ clk_i                                       _*_ _*_
- fp_b_reg samples fp_b_i @ clk_i                                       _*_ _*_
- if rst_i is high, valid_reg samples 0       @ clk_i                   _*_ _*_
- if rst_i is low,  valid_reg samples valid_i @ clk_i                   _*_ _*_

Main:
- check widths                                                          _*_ _*_
- sign, exp and frac_ex starting values                                 _*_ _*_

then

- if fp_b_frac_ex[0] == 1 (this is the round bit), then we              _*_ _*_
 add 1 to fp_b_frac_ex.
- The logic is as such:
    - with the context of the previous round (ngm),                     _*_ _*_
    - the carry bit 0                                                   _*_ _*_
    - if a shift happened, the lead bit will become zero                _*_ _*_
      and the round bit could be 1. In this case, adding 1
      will not cause the carry bit to be 1, since the lead 
      bit itself is 0, hence it is correct.
    - if a shift didn't happen, the round bit will be 0,                _*_ _*_
      which means we won't add a 1 (everything stays the 
      same)
    - don't arbritrarily add a 1, setting the round bit to              _*_ _*_
      1 when it's 0 will affect calculations down the line!
      (you must check the round bit)

Output:     
- fp_a_o is fp_a_reg                                                    _*_ _*_
- fp_b_o is the concatenation of fp_b_sign, fp_b_exp, fp_b_frac_ex      _*_ _*_
- valid_o is valid_reg                                                  _*_ _*_

Log:
- rnv has been verified by me (7/8/25)
- rnv has been verfied by me (7/14/25)

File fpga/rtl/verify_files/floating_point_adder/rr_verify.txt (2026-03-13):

Round Result

Specification:
- given fp_i, round the result and output in regular form

Descriptions:
- frac ex (expand) describes carry bit, lead bit, frac bits and round bit
  in that order.
- it's just a way to break up the full form into pieces:
    {sign bit, exp bits, frac ex bits} for ease of use

Parameters:
- EXP_WIDTH,  width of exponent part                                    
- FRAC_WIDTH, width of fractional part                                  

'Local' Parameters:
- FRAC_EX_WIDTH, width of frac ex                       
    -> 1 + 1 + FRAC_WIDTH + 1                                       _*_ _*_                                                                                                             
- FRAC_EX_IDX_LSB, lsb index of frac ex 
    -> 0                                                            _*_ _*_                                                                                              
- FRAC_EX_IDX_MSB, msb index of frac ex
    -> FRAC_EX_WIDTH + FRAC_EX_IDX_LSB - 1                          _*_ _*_
- FRAC_IDX_LSB, lsb index of frac
    -> 1                                                            _*_ _*_
- FRAC_IDX_MSB, msb index of frac
    -> FRAC_WIDTH + FRAC_IDX_LSB - 1                                _*_ _*_                                                                      
- EXP_IDX_LSB, lsb index of exp ex
    -> FRAC_EX_WIDTH                                                _*_ _*_                                                                                                 
- EXP_IDX_MSB, msb index of exp ex
    -> EXP_WIDTH + EXP_IDX_LSB - 1                                  _*_ _*_                                                       
- SIGN_IDX, index of sign bit
    -> EXP_WIDTH + FRAC_EX_WIDTH                                    _*_ _*_
- CARRY_IDX, index of carry bit
    -> 1 + FRAC_WIDTH + 1                                           _*_ _*_                            
- FP_WIDTH_TOT, width of total form fp
    -> 1 + EXP_WIDTH + FRAC_EX_WIDTH                                _*_ _*_
- FP_WIDTH_REG, width of regular form fp 
    -> 1 + EXP_WIDTH + FRAC_WIDTH                                   _*_ _*_
- ROUND_IDX, idx of round bit                                       
    -> 0                                                            _*_ _*_
- EXP_MAX, max value of an exponent (INF)
    -> (2**EXP_WIDTH) - 1                                           _*_ _*_

IO:
- check widths                                                          

Input Registers:
- check widths                                                      _*_ _*_                                                      
- fp_reg samples fp_i @ clk_i                                       _*_ _*_     
- if rst_i is high, valid_reg samples 0       @ clk_i               _*_ _*_         
- if rst_i is low,  valid_reg samples valid_i @ clk_i               _*_ _*_

Main:
- check widths                                                      _*_ _*_    
- sign, exp and frac_ex starting values                             _*_ _*_
- exp_const is exp starting value                                   _*_ _*_
- the logic is as such:
    - if round bit is 1, add 1 to frac_ex                           _*_ _*_
then
    - if carry bit, add 1 to exp and right                          _*_ _*_
      shift frac_ex                                                 
then
    - if exp_const is EXP_MAX, set exp to EXP_MAX                   _*_ _*_

Output
- fp_o in regular form is the concatenation of fp_sign, fp_exp,     _*_ _*_
  and fp_ex_frac[FRAC_IDX_MSB : FRAC_IDX_LSB]
- valid_o is valid_reg                                              _*_ _*_

Log:
- rr has been verified by me (7/10/25)
- rr has been verified by me (7/14/25)

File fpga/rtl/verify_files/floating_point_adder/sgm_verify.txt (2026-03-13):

Select Greater Magnitude

Specification:
- Given two floating point numbers fp_a_i and fp_b_i, output fp_a_o and fp_b_o such
that fp_a_o would be the fp with the greater exponent.
- Also find the difference in exponents and pass it down
- Pass the valid signal, reset valid signal to 0 on reset.

Parameters:
- EXP_WIDTH,  width of exponent part                                    _*_
- FRAC_WIDTH, width of fractional part                                  _*_

'Local' Parameters:
- SIGN_IDX, the index of the sign bit 
    -> FRAC_WIDTH + EXP_WIDTH                                           _*_ _*_
- EXP_IDX_LSB, the lsb index of the exp bits 
    -> FRAC_WIDTH                                                       _*_ _*_  
- EXP_IDX_MSB, the msb index of the exp bits 
    -> EXP_IDX_LSB + EXP_WIDTH - 1                                      _*_ _*_
- FRAC_IDX_LSB, the lsb index of the sign bit 
    -> 0                                                                _*_ _*_
- FRAC_IDX_MSB, the msb index of the frac bits
    -> FRAC_WIDTH + FRAC_IDX_LSB - 1                                    _*_ _*_
- FP_WIDTH_REG, width of fp in regular form 
    -> 1 + EXP_WIDTH + FRAC_WIDTH                                       _*_ _*_
- FP_WIDTH_TOT, width of fp in total form
    -> 1 + EXP_WIDTH + 1 + 1 + FRAC_WIDTH + 1                           _*_ _*_

IO:
- check widths are set with correct parameters                          _*_ _*_

Input Registers:
- check widths                                                          _*_ _*_
- fp_a_reg samples fp_a_i @ clk_i                                       _*_ _*_
- fp_b_reg samples fp_b_i @ clk_i                                       _*_ _*_
- if rst_i is high, valid_reg samples 0       @ clk_i                   _*_ _*_
- if rst_i is low,  valid_reg samples valid_i @ clk_i                   _*_ _*_

Main:
- check widths                                                          _*_ _*_
- values are set for sign, exp, carry, lead, frac, round for fp_a_* and fp_b_*
    -> carry is 0                                                       _*_ _*_                                          
    -> lead  is 1                                                       _*_ _*_
    -> round is 0                                                       _*_ _*_
- *_sign is SIGN_IDX                                                    _*_ _*_
- *_exp is [EXP_IDX_MSB : EXP_IDX_LSB]                                  _*_ _*_
- *_frac is [FRAC_IDX_MSB: FRAC_IDX_LSB]                                _*_ _*_

then

- if fp_*_exp is 0, this means that it is a subnormal value, and the    _*_ _*_
  fp_*_lead is set to 0 and fp_*_exp is set to 1
- fp_*_exp are declared as unsigned, comparison to 0 is correct         _*_ _*_                        

then

- the tmp_* default values are set to fp_a_* values                     _*_ _*_
- check types are the same                                              _*_ _*_

then 

- fp_a_exp, fp_b_exp, both are declared as unsigned, hence this         _*_ _*_
  comparison is correct                                                   
- if fp_a_exp is smaller than fp_b_exp, we need to swap all their       _*_ _*_
  values, this is done using the tmp_* which holds the fp_a_* values    

then
- exp_diff is fp_a_exp - fp_b_exp, there is no chance of underflow since
  fp_a_exp is greater than or equal to fp_b_exp (from previous step)    _*_ _*_ 
- type is the same                                                      _*_ _*_

Output:
- fp_*_o is the concatenation of the fp_*_* signals in this order:
    sign bit, exp bits, carry bit, lead bit, frac bits, round bit       _*_ _*_
- valid_o is valid_reg                                                  _*_ _*_
- exp_diff_o is exp_diff                                                _*_ _*_

Log:
- sgm has been verified by me (7/8/25)
- smg has been verified by me (7/14/25)

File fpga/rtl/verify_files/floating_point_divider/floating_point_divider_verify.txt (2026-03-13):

Divide Two Floating Point Numbers

Specification:
- given two fp numbers, fp_a_i and fp_b_i, divide them together and
produce fp_o

Descriptions:
- frac ex (expand) describes carry bit, lead bit, frac bits and round bit
  in that order.
- it's just a way to break up the full form into pieces:
    {sign bit, exp bits, frac ex bits} for ease of use

Parameters:
- EXP_WIDTH,  width of exponent part                                    _*_
- FRAC_WIDTH, width of fractional part                                  _*_

'Local' Parameters:
- SIGN_IDX, the index of the sign bit                                   _*_                          
    -> FRAC_WIDTH + EXP_WIDTH                                           
- EXP_IDX_LSB, the lsb index of the exp bits                            _*_
    -> FRAC_WIDTH                                                         
- EXP_IDX_MSB, the msb index of the exp bits                            _*_
    -> EXP_IDX_LSB + EXP_WIDTH - 1                                      
- FRAC_IDX_LSB, the lsb index of the sign bit                           _*_         
    -> 0                                                                
- FRAC_IDX_MSB, the msb index of the frac bits                          _*_
    -> FRAC_WIDTH + FRAC_IDX_LSB - 1                                    
- FP_WIDTH_REG, width of fp in regular form                             _*_
    -> 1 + EXP_WIDTH + FRAC_WIDTH                                       
- FP_WIDTH_TOT, width of fp in total form                               _*_
    -> 1 + EXP_WIDTH + 1 + 1 + FRAC_WIDTH + 1
- FRAC_EX_WIDTH, width of frac ex                                       _*_
    -> 1 + 1 + FRAC_WIDTH + 1
- FRAC_EX_MULT_WIDTH, width of fp in total form                         _*_
  *2 (for when its multiplied)
    -> 2  * FRAC_EX_WIDTH
- BIAS, exponent bias                                                   _*_
    -> 2**(EXP_WIDTH - 1) - 1
- EXP_MAX, max exponent unsigned                                        _*_  
    -> 2**EXP_WIDTH - 1
- FRAC_DIV_WIDTH , width of divided numbers                             
    -> FRAC_EX_WIDTH + 2

IO:
- check widths                                                          _*_  

Input Registers:
- check widths                                                          _*_                                                
- fp_*_reg samples fp_*_i                    @ clk_i                    _*_                                  
- if rst_i is high, valid_reg samples 0      @ clk_i                    _*_
- if rst_i is low, valid_reg samples valid_i @ clk_i                    _*_

-- Entry --
- The exponent logic was doing using the fp mutliplier proofing         _*_ 
- same with fp_sign   
- fp_a_zero and fp_b_zero set when subnormal detected                   _*_
- fp_*_frac_div is {1'b0, fp_*_frac_ex, 1'b0}                           _*_
- fp_quotient_start is 0                                                _*_

-- Div part --
- format is dividend/divisor = quotient
-  check input registers and width                                      _*_
- if dividend >= divisor, set quotient at Q_IDX to 1 and subtract the   _*_
  divisor 
- else set the quotient at Q_IDX to 0                                   _*_
- dividend becomes dividend << 1                                        _*_
- divisor stays the same                                                _*_
- check outputs                                                         _*_
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

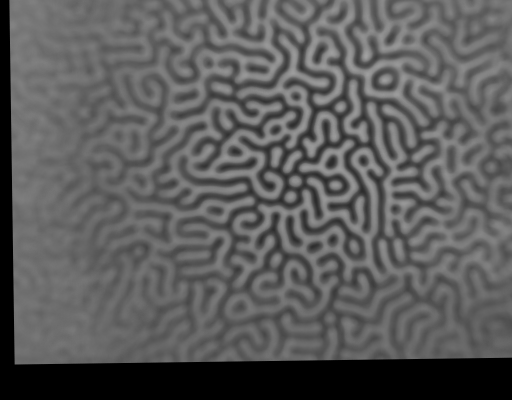
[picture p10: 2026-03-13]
fpga/tb/dfdd_tb/test_images/capture_36_camera1.png

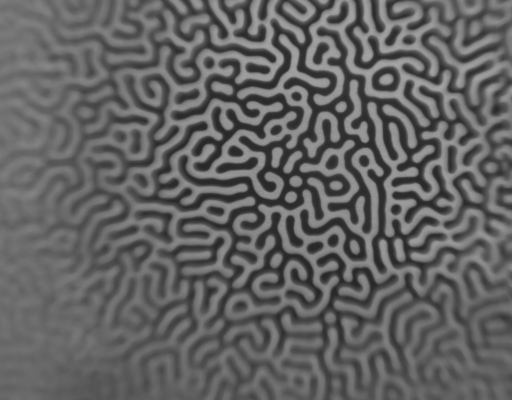
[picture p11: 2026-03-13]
fpga/tb/dfdd_tb/test_images/capture_36_camera0.png

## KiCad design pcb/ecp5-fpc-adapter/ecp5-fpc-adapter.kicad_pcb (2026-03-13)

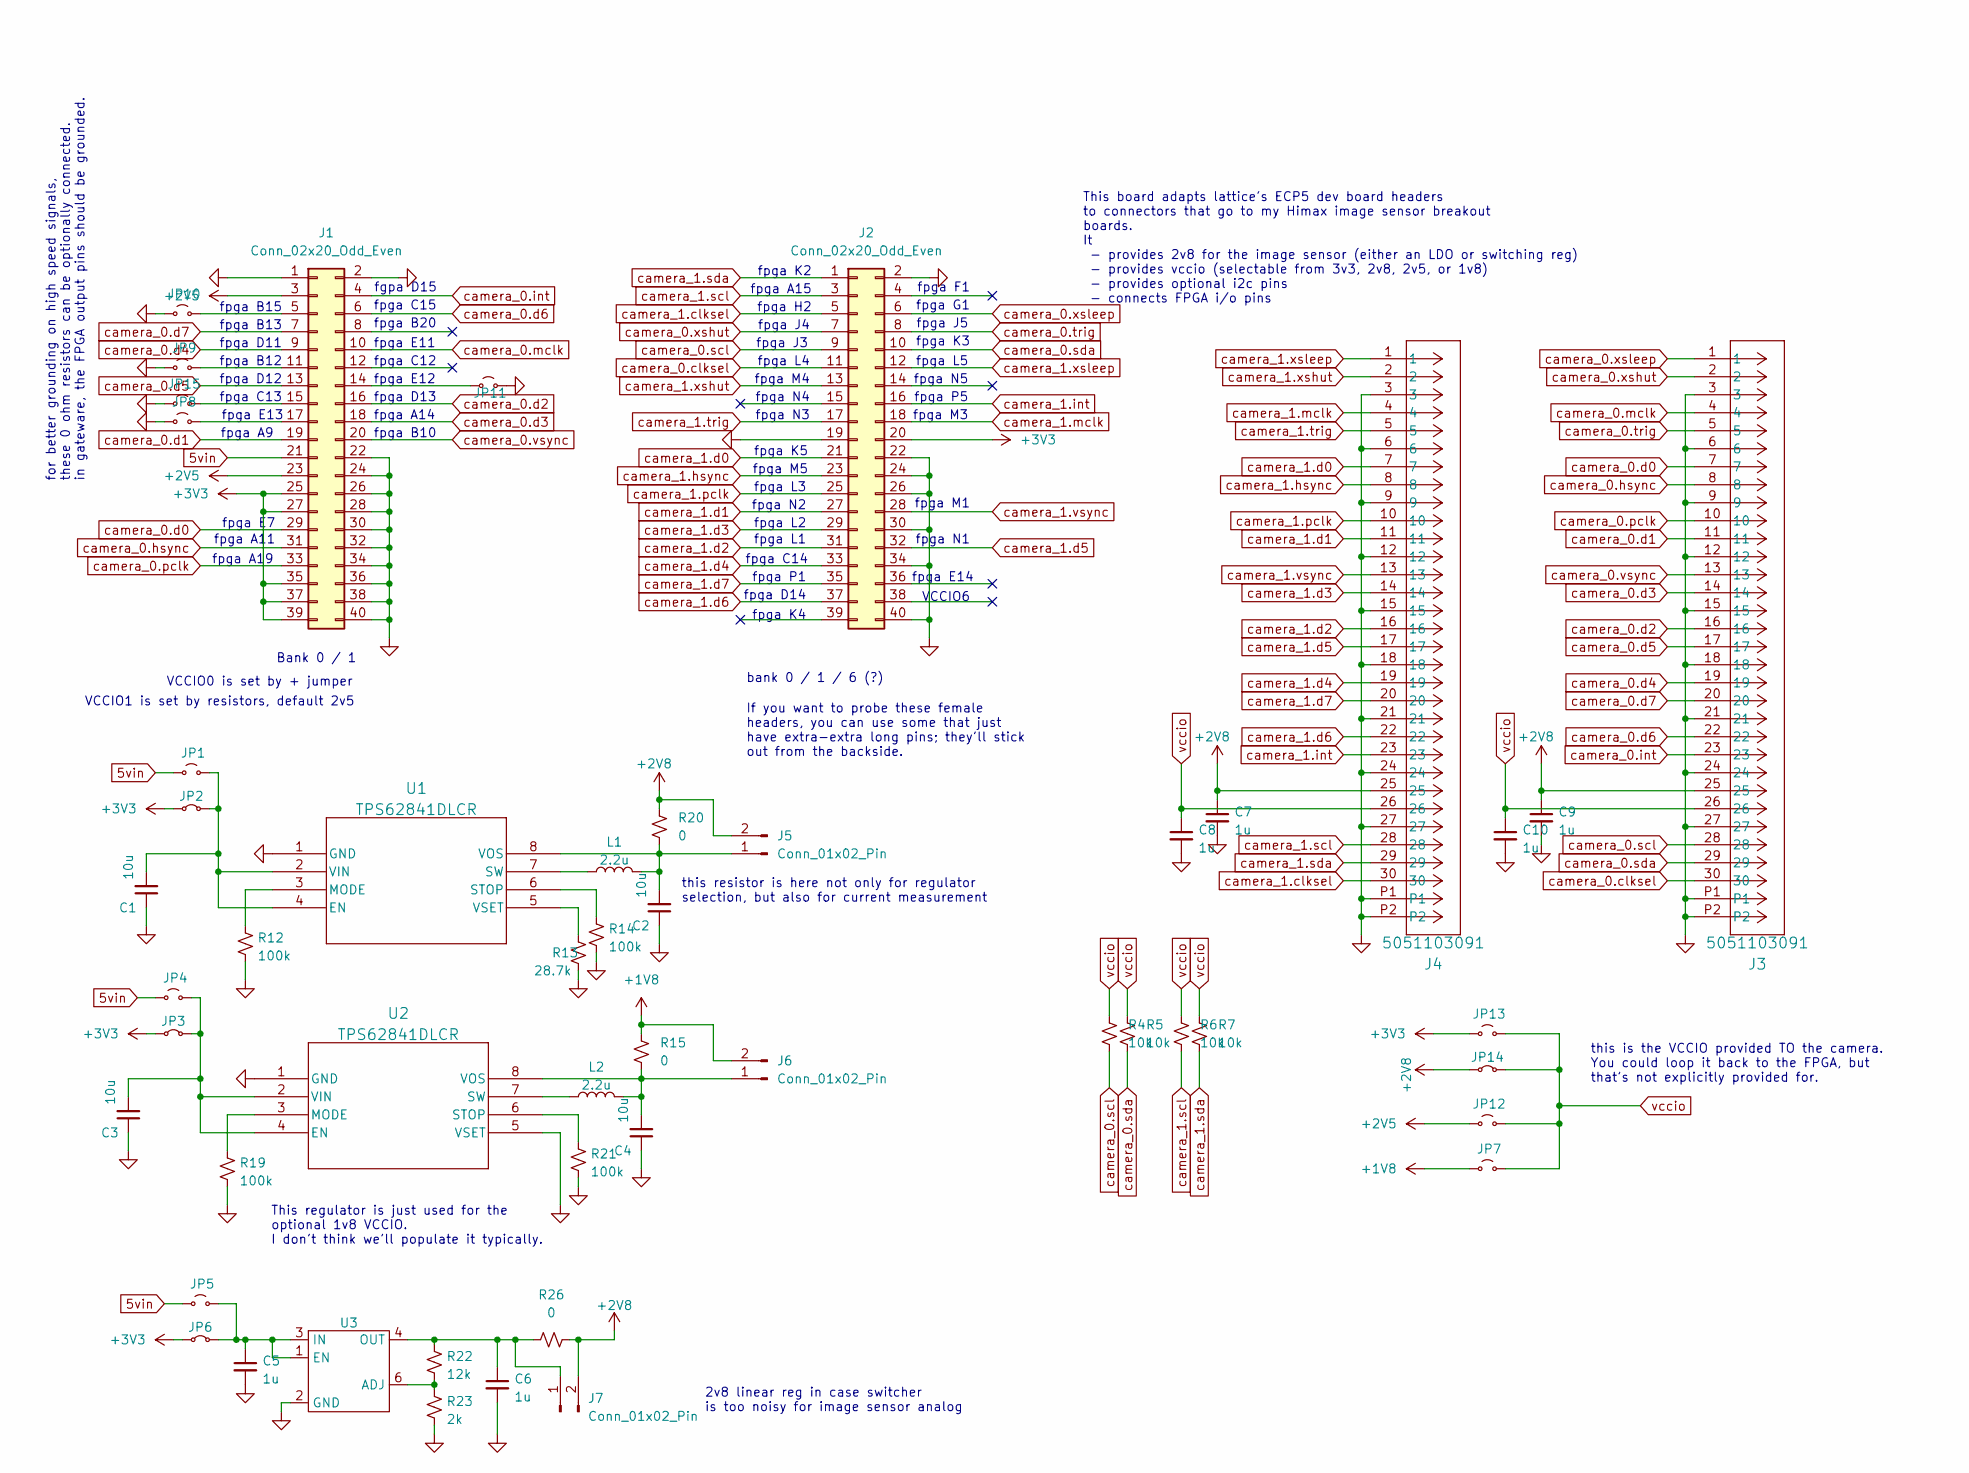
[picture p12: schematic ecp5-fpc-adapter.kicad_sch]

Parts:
C1, C2, C3, C4: 10u; C_0603_1608Metric_Pad1.08x0.95mm_HandSolder; MFR_PN CL21A106KOQNNNE
C5, C6, C7, C8, C9, C10: 1u; C_0603_1608Metric_Pad1.08x0.95mm_HandSolder; MFR_PN CL05A105KO5NNNC
J1, J2: Conn_02x20_Odd_Even; PinHeader_2x20_P2.54mm_Vertical
J3, J4: 5051103091; CON_5051103091_MOL
J5, J6, J7: Conn_01x02_Pin; PinHeader_1x02_P2.54mm_Vertical
JP1, JP4, JP5, JP7, JP8, JP9, JP10, JP11, JP12, JP13, JP15: Jumper_2_Small_Open; SolderJumper-2_P1.3mm_Open_RoundedPad1.0x1.5mm
JP2, JP3, JP6, JP14: Jumper_2_Small_Bridged; SolderJumper-2_P1.3mm_Bridged_RoundedPad1.0x1.5mm
L1, L2: 2.2u; IND_DFE2016_MUR; MFR_PN DFE201612E-2R2M=P2
R4, R5, R6, R7: 10k; R_0603_1608Metric_Pad0.98x0.95mm_HandSolder; MFR_PN ERJ-2GE0R00X
R12, R14, R19, R21: 100k; R_0603_1608Metric_Pad0.98x0.95mm_HandSolder; MFR_PN ERJ-2RKF5101X
R13: 28.7k; R_0603_1608Metric_Pad0.98x0.95mm_HandSolder; MFR_PN ERJ-2RKF5101X
R15, R20, R26: 0; R_0603_1608Metric_Pad0.98x0.95mm_HandSolder; MFR_PN ERJ-2GE0R00X
R22: 12k; R_0603_1608Metric_Pad0.98x0.95mm_HandSolder; MFR_PN ERJ-2RKF1202X
R23: 2k; R_0603_1608Metric_Pad0.98x0.95mm_HandSolder; MFR_PN ERJ-2RKF2001X
U1, U2: TPS62841DLCR; VSON8_2P1X1P6_TEX
U3: AP7331-SNG-7; DFN200X200X60-8N; MFR_PN AP7331-SNG-7

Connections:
5vin: J1.21, JP1.1 (A), JP4.1 (A), JP5.1 (A)
+1V8: J6.2, JP7.1 (A), R15.2
+2V5: J1.3, J1.23, JP12.1 (A)
+2V8: C7.1, C9.1, J3.25, J4.25, J5.2, J7.2, JP14.1 (A), R20.2, R26.1
+3V3: J1.25, J1.27, J1.35, J1.37, J1.39, J2.20, JP2.1 (A), JP3.1 (A), JP6.1 (A), JP13.1 (A)
GND: C1.1, C2.1, C3.1, C4.1, C5.2, C6.2, C7.2, C8.2, C9.2, C10.2, J1.1, J1.2, J1.22, J1.24, J1.26, J1.28, J1.30, J1.32, J1.34, J1.36, J1.38, J1.40, J2.2, J2.19, J2.22, J2.24, J2.26, J2.30, J2.34, J2.40, J3.3, J3.6, J3.9, J3.12, J3.15, J3.18, J3.21, J3.24, J3.27, J3.P1, J3.P2, J4.3, J4.6, J4.9, J4.12, J4.15, J4.18, J4.21, J4.24, J4.27, J4.P1, J4.P2, JP8.1 (A), JP9.1 (A), JP10.1 (A), JP11.2 (B), JP15.1 (A), R12.2, R13.2, R14.2, R19.2, R21.2, R23.2, U1.1 (GND), U2.1 (GND), U2.5 (VSET), U3.2 (GND), U3.7 (GNDPAD1), U3.8 (GNDPAD2)
unnamed: J1.5, JP10.2 (B)
unnamed: J1.11, JP9.2 (B)
unnamed: J1.14, JP11.1 (A)
unnamed: J1.15, JP15.2 (B)
unnamed: J1.17, JP8.2 (B)
unnamed: C2.2, J5.1, L1.2, R20.1, U1.8 (VOS)
unnamed: C4.2, J6.1, L2.2, R15.1, U2.8 (VOS)
unnamed: C6.1, J7.1, R22.1, R26.2, U3.4 (OUT)
unnamed: C1.2, JP1.2 (B), JP2.2 (B), U1.2 (VIN), U1.4 (EN)
unnamed: C3.2, JP3.2 (B), JP4.2 (B), U2.2 (VIN), U2.4 (EN)
unnamed: C5.1, JP5.2 (B), JP6.2 (B), U3.1 (EN), U3.3 (IN)
unnamed: R12.1, U1.3 (MODE)
unnamed: R14.1, U1.6 (STOP)
unnamed: L1.1, U1.7 (SW)
unnamed: R13.1, U1.5 (VSET)
unnamed: R19.1, U2.3 (MODE)
unnamed: R21.1, U2.6 (STOP)
unnamed: L2.1, U2.7 (SW)
unnamed: R22.2, R23.1, U3.6 (ADJ)
camera_0.clksel: J2.11, J3.30
camera_0.d0: J1.29, J3.7
camera_0.d1: J1.19, J3.11
camera_0.d2: J1.16, J3.16
camera_0.d3: J1.18, J3.14
camera_0.d4: J1.9, J3.19
camera_0.d5: J1.13, J3.17
camera_0.d6: J1.6, J3.22
camera_0.d7: J1.7, J3.20
camera_0.hsync: J1.31, J3.8
camera_0.int: J1.4, J3.23
camera_0.mclk: J1.10, J3.4
camera_0.pclk: J1.33, J3.10
camera_0.scl: J2.9, J3.28, R4.1
camera_0.sda: J2.10, J3.29, R5.1
camera_0.trig: J2.8, J3.5
camera_0.vsync: J1.20, J3.13
camera_0.xshut: J2.7, J3.2
camera_0.xsleep: J2.6, J3.1
camera_1.clksel: J2.5, J4.30
camera_1.d0: J2.21, J4.7
camera_1.d1: J2.27, J4.11
camera_1.d2: J2.31, J4.16
camera_1.d3: J2.29, J4.14
camera_1.d4: J2.33, J4.19
camera_1.d5: J2.32, J4.17
camera_1.d6: J2.37, J4.22
camera_1.d7: J2.35, J4.20
camera_1.hsync: J2.23, J4.8
camera_1.int: J2.16, J4.23
camera_1.mclk: J2.18, J4.4
camera_1.pclk: J2.25, J4.10
camera_1.scl: J2.3, J4.28, R6.1
camera_1.sda: J2.1, J4.29, R7.1
camera_1.trig: J2.17, J4.5
camera_1.vsync: J2.28, J4.13
camera_1.xshut: J2.13, J4.2
camera_1.xsleep: J2.12, J4.1
vccio: C8.1, C10.1, J3.26, J4.26, JP7.2 (B), JP12.2 (B), JP13.2 (B), JP14.2 (B), R4.2, R5.2, R6.2, R7.2

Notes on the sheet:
fpga E14
fpga E13
fpga N1
fpga D13
fpga E12
this is the VCCIO provided TO the camera. You could loop it back to the FPGA, but that's not explicitly provided for.
fpga K5
fpga B20
fpga J4
fpga B10
fpga L5
fpga L3
fpga B13
fpga M3
fpga A9
fpga L1
fpga M1
fpga A15
fpga H2
fpga N4
fpga C13
fpga K2
fpga J3
fpga N3
fpga F1
fpga C12
bank 0 / 1 / 6 (?)
this resistor is here not only for regulator selection, but also for current measurement
This board adapts lattice's ECP5 dev board headers to connectors that go to my Himax image sensor breakout boards. It - provides 2v8 for the image sensor (either an LDO or switching reg) - provides vccio (selectable from 3v3, 2v8, 2v5, or 1v8) - provides optional i2c pins - connects FPGA i/o pins
fpga E7
fpga B12
fpga J5
fpga D12
fpga P5
If you want to probe these female headers, you can use some that just have extra-extra long pins; they'll stick out from the backside.
fpga A19
fpga K3
fpga B15
fpga N5
fpga M4

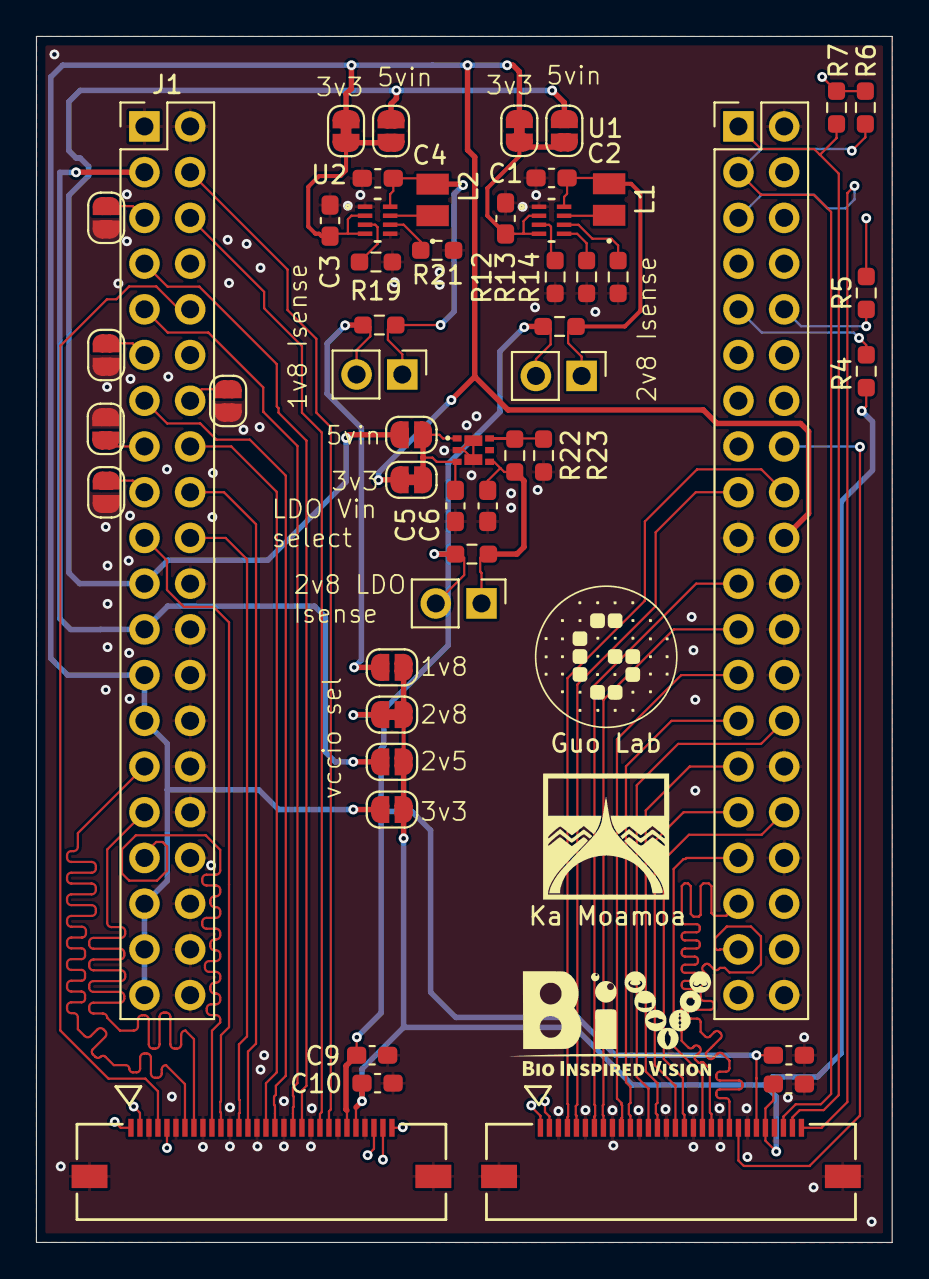
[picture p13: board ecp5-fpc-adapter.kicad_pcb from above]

Board: 4 copper layers, 47.5 x 67.0 mm, 51 parts (0 on the bottom side), 64 nets.

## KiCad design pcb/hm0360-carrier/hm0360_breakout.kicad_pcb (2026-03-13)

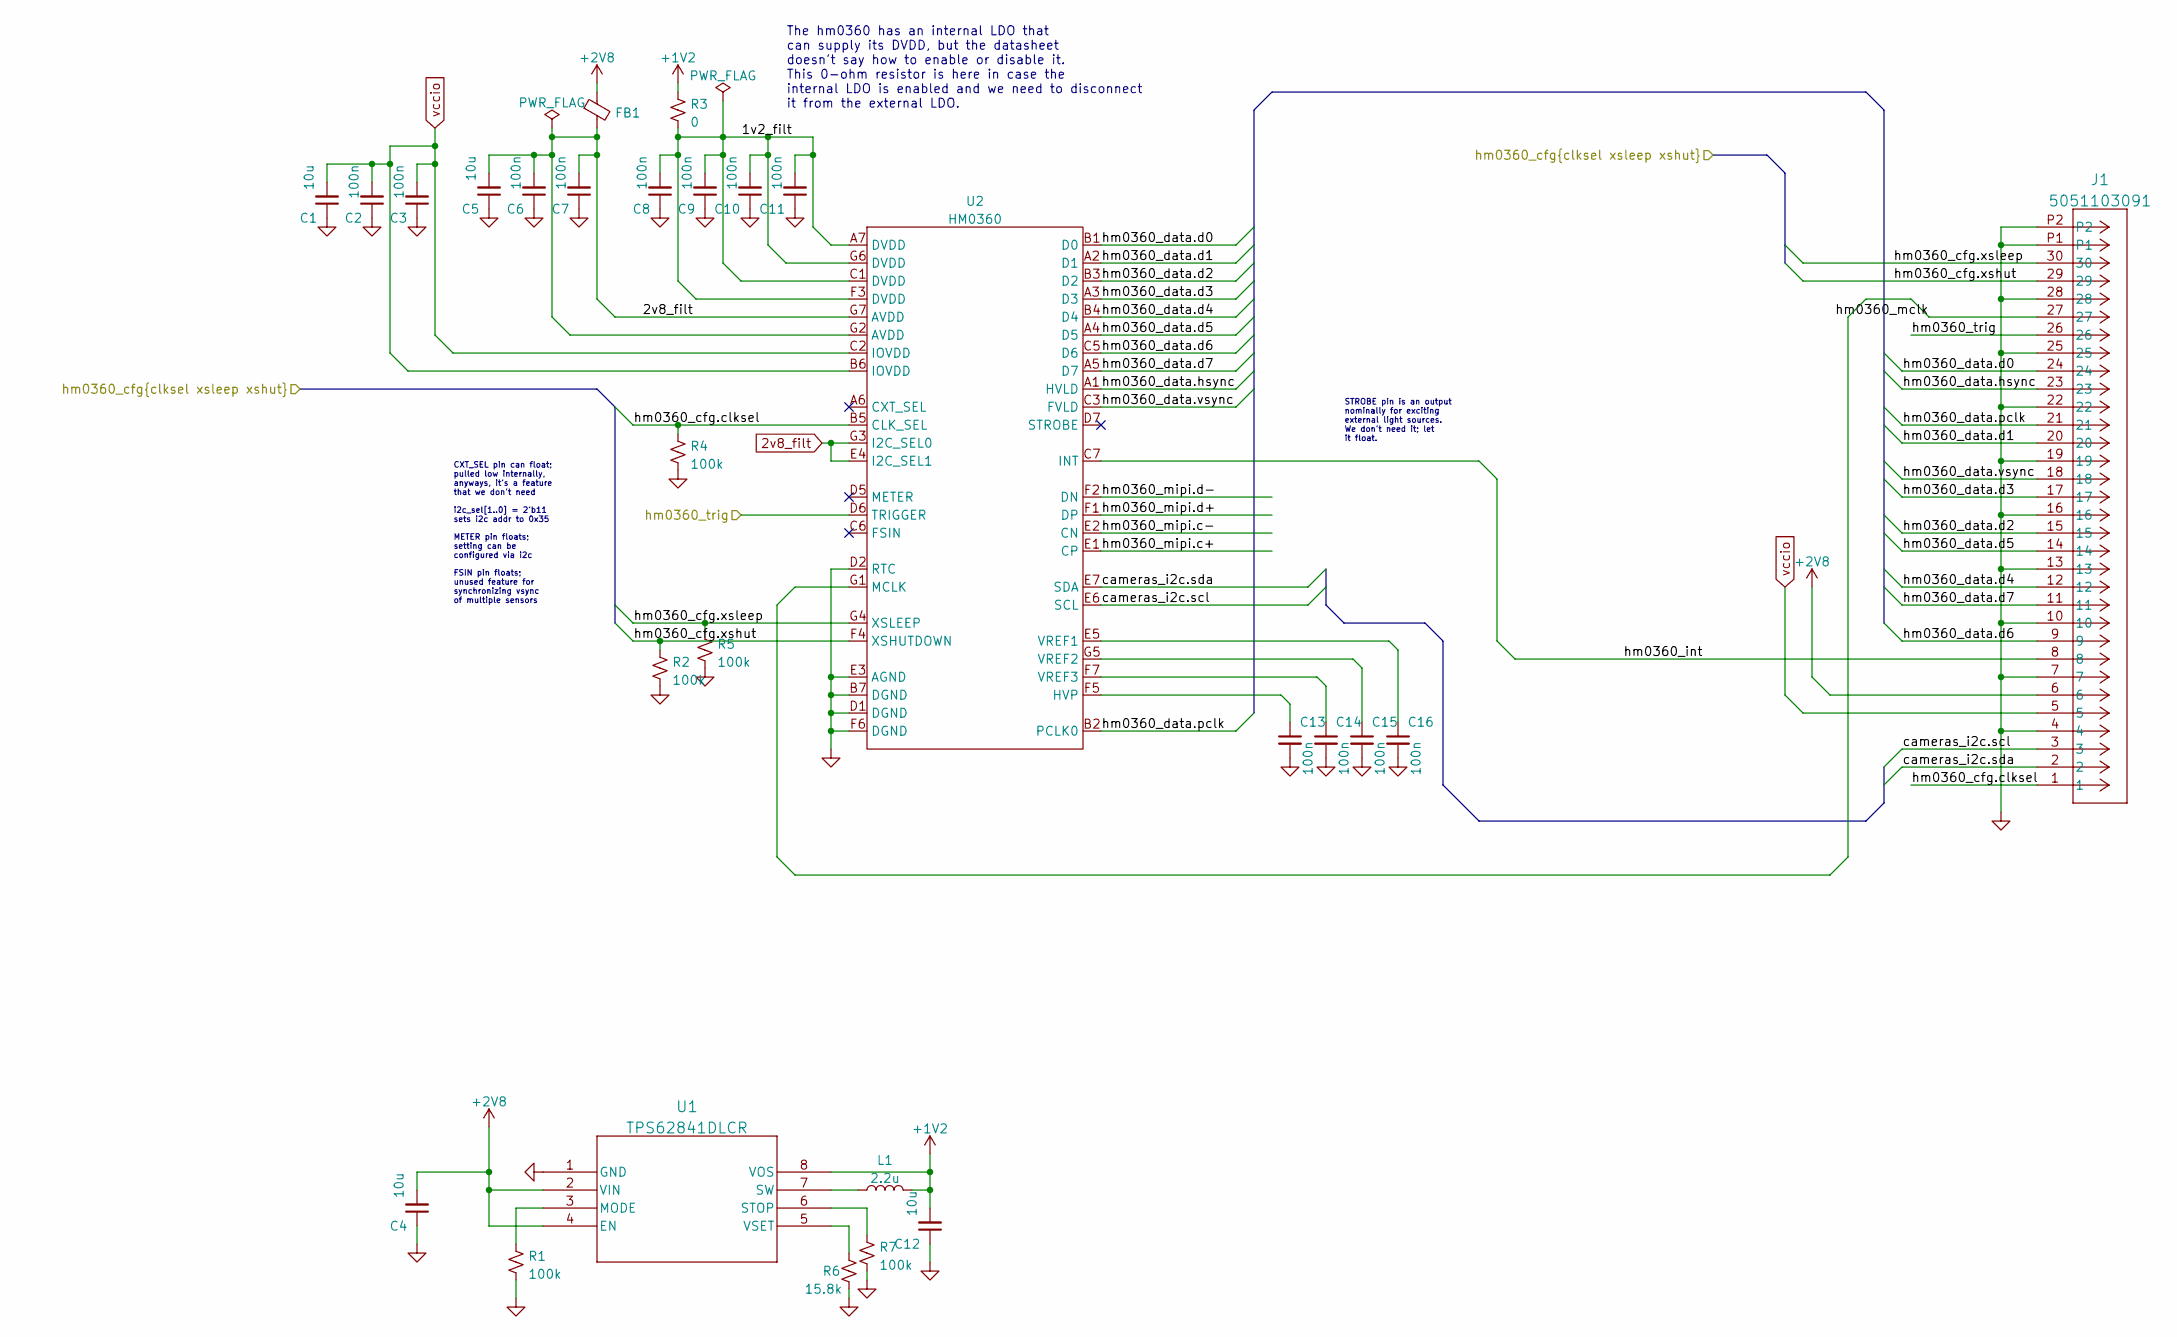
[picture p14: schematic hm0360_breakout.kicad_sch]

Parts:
C1, C4, C5, C12: 10u; C_0603_1608Metric; MFR_PN CL21A106KOQNNNE
C2, C3, C6, C7, C8, C9, C10, C11, C13, C14, C15, C16: 100n; C_0201_0603Metric; MFR_PN CL05B104KP5NNNC
FB1: FerriteBead_Small; C_0603_1608Metric; MFR_PN MPZ1608B471ATA00
J1: 5051103091; CON_5051103091_MOL
L1: 2.2u; IND_DFE2016_MUR; MFR_PN DFE201612E-2R2M=P2
R1, R2, R4, R5, R7: 100k; R_0201_0603Metric; MFR_PN ERJ-2RKF5101X
R3: 0; R_0201_0603Metric; MFR_PN ERJ-2GE0R00X
R6: 15.8k; R_0402_1005Metric; MFR_PN ERJ-2RKF5101X
U1: TPS62841DLCR; VSON8_2P1X1P6_TEX
U2: HM0360; hm0360; MFR_PN HM0360-MWA

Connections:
2v8_filt: C5.2, C6.2, C7.2, FB1.2, U2.E4 (I2C_SEL1), U2.G2 (AVDD), U2.G3 (I2C_SEL0), U2.G7 (AVDD)
+1V2: C12.2, L1.2, R3.1, U1.8 (VOS)
+2V8: C4.2, FB1.1, J1.6, U1.2 (VIN), U1.4 (EN)
/1v2_filt: C8.2, C9.2, C10.2, C11.2, R3.2, U2.A7 (DVDD), U2.C1 (DVDD), U2.F3 (DVDD), U2.G6 (DVDD)
/cameras_i2c.scl: J1.3, U2.E6 (SCL)
/cameras_i2c.sda: J1.2, U2.E7 (SDA)
/hm0360_cfg.clksel: J1.1, R4.1, U2.B5 (CLK_SEL)
/hm0360_cfg.xshut: J1.29, R2.1, U2.F4 (XSHUTDOWN)
/hm0360_cfg.xsleep: J1.30, R5.1, U2.G4 (XSLEEP)
/hm0360_data.d0: J1.24, U2.B1 (D0)
/hm0360_data.d1: J1.20, U2.A2 (D1)
/hm0360_data.d2: J1.15, U2.B3 (D2)
/hm0360_data.d3: J1.17, U2.A3 (D3)
/hm0360_data.d4: J1.12, U2.B4 (D4)
/hm0360_data.d5: J1.14, U2.A4 (D5)
/hm0360_data.d6: J1.9, U2.C5 (D6)
/hm0360_data.d7: J1.11, U2.A5 (D7)
/hm0360_data.hsync: J1.23, U2.A1 (HVLD)
/hm0360_data.pclk: J1.21, U2.B2 (PCLK0)
/hm0360_data.vsync: J1.18, U2.C3 (FVLD)
/hm0360_int: J1.8, U2.C7 (INT)
/hm0360_mclk: J1.27, U2.G1 (MCLK)
/hm0360_mipi.c+: U2.E1 (CP)
/hm0360_mipi.c-: U2.E2 (CN)
/hm0360_mipi.d+: U2.F1 (DP)
/hm0360_mipi.d-: U2.F2 (DN)
/hm0360_trig: J1.26, U2.D6 (TRIGGER)
GND: C1.1, C2.1, C3.1, C4.1, C5.1, C6.1, C7.1, C8.1, C9.1, C10.1, C11.1, C12.1, C13.2, C14.2, C15.2, C16.2, J1.4, J1.7, J1.10, J1.13, J1.16, J1.19, J1.22, J1.25, J1.28, J1.P1, J1.P2, R1.2, R2.2, R4.2, R5.2, R6.2, R7.2, U1.1 (GND), U2.B7 (DGND), U2.D1 (DGND), U2.D2 (RTC), U2.E3 (AGND), U2.F6 (DGND)
unnamed: C13.1, U2.F5 (HVP)
unnamed: C14.1, U2.F7 (VREF3)
unnamed: C15.1, U2.G5 (VREF2)
unnamed: C16.1, U2.E5 (VREF1)
unnamed: L1.1, U1.7 (SW)
unnamed: R1.1, U1.3 (MODE)
unnamed: R6.1, U1.5 (VSET)
unnamed: R7.1, U1.6 (STOP)
vccio: C1.2, C2.2, C3.2, J1.5, U2.B6 (IOVDD), U2.C2 (IOVDD)

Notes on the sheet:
FSIN pin floats; unused feature for synchronizing vsync of multiple sensors
CXT_SEL pin can float; pulled low internally, anyways, it's a feature that we don't need
STROBE pin is an output nominally for exciting external light sources. We don't need it; let it float.
i2c_sel[1..0] = 2'b11 sets i2c addr to 0x35
The hm0360 has an internal LDO that can supply its DVDD, but the datasheet doesn't say how to enable or disable it. This 0-ohm resistor is here in case the internal LDO is enabled and we need to disconnect it from the external LDO.
METER pin floats; setting can be configured via i2c

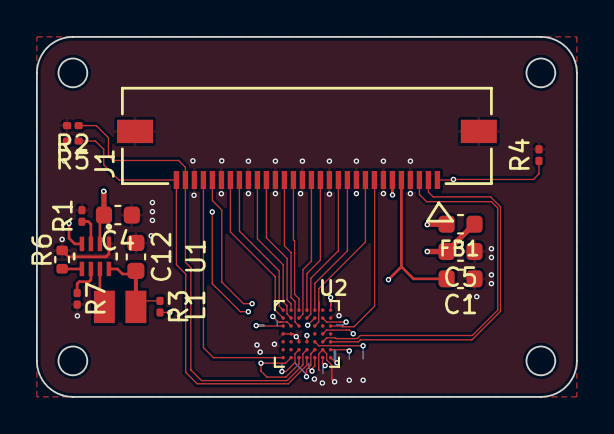
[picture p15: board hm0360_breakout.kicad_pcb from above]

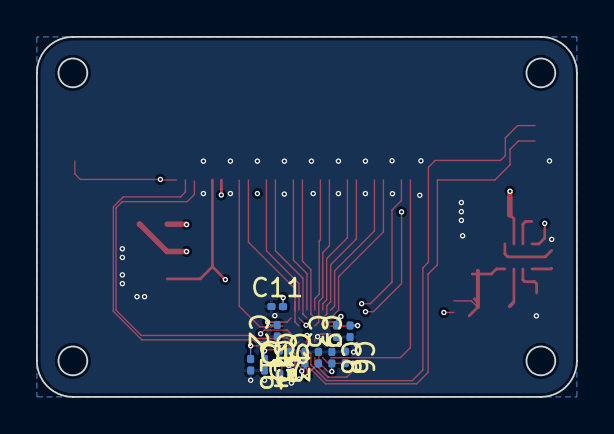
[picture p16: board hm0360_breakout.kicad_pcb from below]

Board: 4 copper layers, 30.0 x 20.0 mm, 28 parts (12 on the bottom side), 33 nets.

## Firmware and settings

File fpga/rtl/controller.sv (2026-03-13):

/*
 * Simple Controller that drives the constants
 * and two bilinear xform matrix values
 * Memory Map:
 * Homography matricies
 * ----------------------------
 * 0x10 -> 0x18 - Bilinear transform matrix for camera 0
 * 0x20 -> 0x28 - Bilinear transform matrix for camera 1
 *
 * Roi boundaries
 * ----------------------------
 * All roi's are fixed size - their dims are determined
 * (0x80, 0x81) - top-left corner of roi pre-bilinear-xform roi (y, x). roi is fixed-size
 * (0x82, 0x83) - top-left corner of roi post-bilinear-xform roi (y, x).
 *
 *
 * DfDD constants, 2 scale setup - each 2 bytes
 * ----------------------------
 * A and B are variable, with 16 zones
 *
 * 0xA0 -> 0xAF - Scale 0, A values per zone
 * 0x90 -> 0x9F - Scale 1, A values per zone
 * 0xB0 -> 0xBF - Scale 0, B values per zone
 * 0xF0 -> 0xFF - Scale 1, B values per zone
 * 0x70 -> 0x7F - radius squared values
 * 0xC0 -> 0xC1 - w0
 * 0xD0 -> 0xD1 - w1
 * 0xE0 -> 0xE1 - w2
 * 
 * Confidence Minimum, 16 zones
 * ----------------------------
 * 0x50 -> 0x5F - 2 bytes
 *
 * Depth Maximum, 16 zones
 * ----------------------------
 * 0x00 -> 0x0F - 2 bytes
 * 
 * Depth Minimum, 16 zones
 * ----------------------------
 * 0x30 -> 0x3F
 *
 *
 *
 * Col and Row center
 * ----------------------------
 * 0x60 - col center
 * 0x61 - row center
 *
 * rest has no effect.
 *
 * Default (reset) parameters should be fully defined.
 */

module controller #(
    parameter FP_M_K = 2,
    parameter FP_N_K = 12,
    parameter FP_S_K = 1,

    parameter PRECISION = 0,

    // Default Values for Constants
    parameter [15:0] A  [2][16] = {default: 16'h3c00},

    parameter [15:0] B  [2][16] = {default: 16'h3c00},

    parameter [17:0] R_SQUARED[16] = '{default : 16'h0000},

    parameter [15:0] COL_CENTER = 16'h00C8,
    parameter [15:0] ROW_CENTER = 16'h00C8,

    parameter [15:0] W0 [2] = '{16'h3c00, 16'h3c00},
    parameter [15:0] W1 [2] = '{16'h3c00, 16'h3c00},
    parameter [15:0] W2 [2] = '{16'h3c00, 16'h3c00},

    parameter [15:0] DEFAULT_CONFIDENCE_MINIMUM [16] = '{default : 16'h0000},
    parameter [15:0] DEFAULT_DEPTH_MAXIMUM [16] = '{default : 16'h7fff},
    parameter [15:0] DEFAULT_DEPTH_MINIMUM [16] = '{default : 16'h0000},

    // default values for ROIs
    parameter logic [15:0] DEFAULT_PRE_XFORM_ROI_CORNER [2] = '{ 0, 0},
    parameter logic [15:0] DEFAULT_POST_XFORM_ROI_CORNER [2] = '{ 0, 0},

    // fixed height and width for ROIs
    parameter logic [15:0] PRE_XFORM_ROI_DIMS [2] = '{480, 512},
    parameter logic [15:0] POST_XFORM_ROI_DIMS [2] = '{480, 512},

    // default values for bilinear matrices
    parameter [11+PRECISION-1:0] BILINEAR_1 = 19'b000_0000_0001_0000_0000,
    parameter [11+PRECISION-1:0] DEFAULT_BILINEAR_MATRICES [3][3]
        = '{{BILINEAR_1,0,0},{0,BILINEAR_1,0},{0,0,BILINEAR_1}}
) (
    input rst_n_i,

    command_interface.writer in,

    output [15:0] a_o            [2][16],
    output [15:0] b_o            [2][16],
    output [17:0] r_squared_o       [16],
    output [15:0] w0_o [2],
    output [15:0] w1_o [2],
    output [15:0] w2_o [2],
    output [15:0] col_center_o,
    output [15:0] row_center_o,

    output [11+PRECISION-1:0] bilinear_matrices_o [2][3][3],

    // top, bottom, left, right
    output logic [15:0] pre_bilinear_roi_boundaries_o [4],
    output logic [15:0] post_bilinear_roi_boundaries_o [4],

    output [15:0] confidence_o [16],
    output [15:0] depth_o [16],
    output [15:0] depth_min_o [16]
);
    localparam CONST_WIDTH = FP_M_K + FP_N_K + FP_S_K;
    localparam MATRIX_WIDTH = 11 + PRECISION;

    logic [in.ADDR_WIDTH-1:0] addr;
    logic [in.DATA_WIDTH-1:0] data;
    logic valid;

    logic [15:0] addr_next;
    logic [31:0] data_next;
    logic valid_next;

    logic [15:0] a  [2][16];
    logic [15:0] b  [2][16];
    logic [17:0] r_squared [16];
    logic [15:0] col_center;
    logic [15:0] row_center;
    logic [15:0] w0 [2];
    logic [15:0] w1 [2];
    logic [15:0] w2 [2];

    logic [15:0] a_next  [2][16];
    logic [15:0] b_next  [2][16];
    logic [17:0] r_squared_next [16];
    logic [15:0] col_center_next;
    logic [15:0] row_center_next;
    logic [15:0] w0_next [2];
    logic [15:0] w1_next [2];
    logic [15:0] w2_next [2];

    logic [MATRIX_WIDTH-1:0] bilinear_matrices [2][3][3];
    logic [MATRIX_WIDTH-1:0] bilinear_matrices_next [2][3][3];

    logic [15:0] pre_bilinear_roi_corner [2];
    logic [15:0] post_bilinear_roi_corner [2];
    logic [15:0] pre_bilinear_roi_corner_next [2];
    logic [15:0] post_bilinear_roi_corner_next [2];

    logic [15:0] confidence [16];
    logic [15:0] confidence_next [16];

    logic [15:0] depth [16];
    logic [15:0] depth_next [16];

    logic [15:0] depth_min [16];
    logic [15:0] depth_min_next [16];

    always_comb begin
        int i, j ,k;

        addr_next = in.addr;
        data_next = in.data;
        valid_next = in.valid;

        a_next = a;
        b_next = b;
        r_squared_next = r_squared;
        col_center_next = col_center;
        row_center_next = row_center;
        w0_next = w0;
        w1_next = w1;
        w2_next = w2;

        bilinear_matrices_next = bilinear_matrices;

        pre_bilinear_roi_corner_next = pre_bilinear_roi_corner;
        post_bilinear_roi_corner_next = post_bilinear_roi_corner;

        confidence_next = confidence;
        depth_next = depth;
        depth_min_next = depth_min;

        // Memory Mappings (written purposefully with independent if statements rather than case)
        if(valid) begin

        // matrix A
        if (addr == 16'h10) bilinear_matrices_next[0][0][0] = data[MATRIX_WIDTH-1:0];
        if (addr == 16'h11) bilinear_matrices_next[0][0][1] = data[MATRIX_WIDTH-1:0];
        if (addr == 16'h12) bilinear_matrices_next[0][0][2] = data[MATRIX_WIDTH-1:0];

        if (addr == 16'h13) bilinear_matrices_next[0][1][0] = data[MATRIX_WIDTH-1:0];
        if (addr == 16'h14) bilinear_matrices_next[0][1][1] = data[MATRIX_WIDTH-1:0];
        if (addr == 16'h15) bilinear_matrices_next[0][1][2] = data[MATRIX_WIDTH-1:0];

        if (addr == 16'h16) bilinear_matrices_next[0][2][0] = data[MATRIX_WIDTH-1:0];
        if (addr == 16'h17) bilinear_matrices_next[0][2][1] = data[MATRIX_WIDTH-1:0];
        if (addr == 16'h18) bilinear_matrices_next[0][2][2] = data[MATRIX_WIDTH-1:0];

        // matrix B
        if (addr == 16'h20) bilinear_matrices_next[1][0][0] = data[MATRIX_WIDTH-1:0];
        if (addr == 16'h21) bilinear_matrices_next[1][0][1] = data[MATRIX_WIDTH-1:0];
        if (addr == 16'h22) bilinear_matrices_next[1][0][2] = data[MATRIX_WIDTH-1:0];

        if (addr == 16'h23) bilinear_matrices_next[1][1][0] = data[MATRIX_WIDTH-1:0];
        if (addr == 16'h24) bilinear_matrices_next[1][1][1] = data[MATRIX_WIDTH-1:0];
        if (addr == 16'h25) bilinear_matrices_next[1][1][2] = data[MATRIX_WIDTH-1:0];
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

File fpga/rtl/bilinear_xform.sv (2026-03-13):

/* Bilinear Interpolation
 *
 * A stream processing version of Bilinear interpolation without
 * having the need of a full size frame buffer.
 *
 * Three key assumptions
 * 1. Input and output image dimensions are the same
 * 2. The geometric transformations are small enough such that it
 *    can 'play nice' within 'N_LINES' ** 2, buffered
 * 3. FP of in = FP of out, if there are accuracy issues, append 0's to
 *    the right of image pixel and add FP_N.
 *
 * There are some nice optimizations we can make that can reduce the multipliers
 * needed in the read/write address calculations to buffer. For the writes its
 * taking advantage of the fact that we know what order the pixels (should) arrive
 * in and for the read its knowing that adjacent pixels have the same address or the
 * +1 (made easier if we can guarantee WIDTH is even, since we will have the same
 * number of odd and even pixels in a line). But what was that saying? "Premature
 * optimization is the root of all evil"...
 *
 * For now, good enough.
 *
 * Note! In the reverse mapper,
 * The row and col numbers will be treated as 11 bit 
 * signed numbers, so we can dedicate more bits to the matrix values.
 * So in reality we have a -1024 <-> 1023 range.
 *
 * PASSTHROUGH assumes no transformation. This is so that it can mimic
 * the data movement of another bilinear_xform without the redundant logic.
 *
 *
 */

 module bilinear_xform #(
    // image dimensions
    parameter WIDTH = 320,
    parameter HEIGHT = 240,

    // How lines to buffer in terms of 
    // power of two (.i.e 2 is 2^2 = 4)
    parameter N_LINES_POW2 = 2,

    // Turns out, the optimal condition to decide where
    // the pipe (buffer) is full and output pixels should
    // being driven is entirely dependant on the transformations
    // done for the reverse mapping. So, it too will be parameterized
    parameter PIPE_ROW = 1,
    parameter PIPE_COL = 0,

    // how precisely should the coordinates be transformed
    // (how many bits for decimal place) 
    parameter PRECISION = 8,

    parameter CLKS_PER_PIXEL = 1,

    parameter PASSTHROUGH = 0
 ) (
    pixel_data_interface.writer in,
    pixel_data_interface.reader out,

    // affine transformation matrix
    input signed [11+PRECISION-1:0] matrix_i [3][3],

    // reset signal
    input rst_n_i
 );
    // this impacts address resolution
    // note the address width will always be using even
    localparam ODD_NO_PIXELS = (WIDTH / 2);
    localparam EVEN_NO_PIXELS = (WIDTH / 2) + (WIDTH % 2);

    // Since the number of lines in the buffer is guaranteed to be
    // a power of 2, we don't have to worry about odd/even
    localparam NO_LINES = (2 ** N_LINES_POW2) / 2;

    localparam ADDR_WIDTH = $clog2(EVEN_NO_PIXELS * NO_LINES);

    // Can't do this unfortunately, not sure why? says
    // "parameter refernce ... not valid when actual interface in the instance
    // is an arrayed instance element or below a generate construct"
    // localparam DATA_WIDTH = in.FP_M + in.FP_N + in.FP_S;

    localparam DATA_DEPTH = EVEN_NO_PIXELS * NO_LINES;
    localparam CLKS_MAX = (CLKS_PER_PIXEL > 6) ? 6 : CLKS_PER_PIXEL;

    ////////////////////////////////////////////////////////////////
    // Row buffer control wires consists of 4 Simple DPRAM
    // split amongst even and odd lines, and then amongst even and 
    // columns.
    //
    // A small 2x2 array will be used to setup the control wires
    //
    // ID | Row , Col
    // ---------------
    // 00 | even, even
    // 01 | even, odd
    // 10 | odd , even
    // 11 | odd , odd  

    // read
    logic [ADDR_WIDTH-1:0] r_rdaddr [0:1][0:1];
    logic [in.FP_M + in.FP_N + in.FP_S-1:0] w_rddata [0:1][0:1];
    logic                  w_rddv [0:1][0:1];
    logic                  r_rden [0:1][0:1];

    // write
    logic [ADDR_WIDTH-1:0] r_wraddr [0:1][0:1];
    logic [in.FP_M + in.FP_N + in.FP_S-1:0] r_wrdata [0:1][0:1];
    logic                  r_wrdv [0:1][0:1];

    ////////////////////////////////////////////////////////////////
    // Buffer instantiation and wiring
    genvar i;
    genvar k;
    generate
        for(i = 0; i < 2; i += 1) begin
            for(k = 0; k < 2; k += 1) begin         
                RAM_2Port #(
                    .WIDTH(in.FP_M + in.FP_N + in.FP_S),
                    .DEPTH(DATA_DEPTH)
                ) sdpram (
                    .i_Wr_Clk(in.clk),
                    .i_Wr_Addr(r_wraddr[i][k]),
                    .i_Wr_DV(r_wrdv[i][k]),
                    .i_Wr_Data(r_wrdata[i][k]),

                    .i_Rd_Clk(out.clk),
                    .i_Rd_Addr(r_rdaddr[i][k]),
                    .i_Rd_En(r_rden[i][k]),
                    .o_Rd_DV(w_rddv[i][k]),
                    .o_Rd_Data(w_rddata[i][k])
                );
                
                /*
                // ECP5 specific RAM instantiation
                ecp5_ram_sdp #(
                    .WIDTH(in.FP_M + in.FP_N + in.FP_S),
                    .DEPTH(DATA_DEPTH)
                ) sdpram (
                    .wr_clk_i(in.clk),
                    .wr_addr_i(r_wraddr[i][k]),
                    .wr_dv_i(r_wrdv[i][k]),
                    .wr_data_i(r_wrdata[i][k]),

                    .rd_clk_i(out.clk),
                    .rd_addr_i(r_rdaddr[i][k]),
                    .rd_en_i(r_rden[i][k]),
                    .rd_dv_o(w_rddv[i][k]),
                    .rd_data_o(w_rddata[i][k])
                );
                */
                          
            end
        end
    endgenerate

    ////////////////////////////////////////////////////////////////
    // Write pixel to buffer combinational logic
    logic [N_LINES_POW2-1:0] colmod_wr;

    always_comb begin
        for(int i = 0; i < 2; i += 1) begin
            for(int k = 0; k < 2; k += 1) begin
                r_wraddr[i][k] = 0;
                r_wrdata[i][k] = 0;
                r_wrdv[i][k] = 0;
            end
        end
        
        colmod_wr = in.row[N_LINES_POW2-1:0];
        r_wrdata[in.row[0]][in.col[0]] = in.pixel;

        if((in.col % 2) == 0) begin
            r_wraddr[in.row[0]][in.col[0]] = ((colmod_wr >> 1) * (EVEN_NO_PIXELS)) + (in.col >> 1);

        end else begin
            r_wraddr[in.row[0]][in.col[0]] = ((colmod_wr >> 1) * ( ODD_NO_PIXELS)) + (in.col >> 1);
        end

        if(in.valid == 1) begin
            r_wrdv[in.row[0]][in.col[0]] = 1;
        end 
    end

    

    // See diagram    
    logic [in.FP_M + in.FP_N + in.FP_S-1:0] Q11;
    logic [in.FP_M + in.FP_N + in.FP_S-1:0] Q21;
    logic [in.FP_M + in.FP_N + in.FP_S-1:0] Q12;
    logic [in.FP_M + in.FP_N + in.FP_S-1:0] Q22;
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

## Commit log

2026-03-13 uploaded fpga code, pcb adapter parts and 3d printed parts models
    [5051103091.stp, Beamsplitter direct mount - Baffle.step, Beamsplitter direct mount - Lid.step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]
2026-03-13 adjusted filenames
    [Beamsplitter_direct_mount_Baffle.step, Beamsplitter_direct_mount_Lid.step, Beamsplitter_direct_mount_iris_Baffle.step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]
2026-03-13 added camera previewer bit file
    [ecp5-evn.cfg]
2026-03-13 Update project title and add calibration section

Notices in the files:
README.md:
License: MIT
